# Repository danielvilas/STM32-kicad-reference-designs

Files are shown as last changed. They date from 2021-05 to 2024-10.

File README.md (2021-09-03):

# STM32-kicad-reference-designs

{:toc}

Reference Designs for STM32 in KiCad

These projects are designed as reference Design for copy subsheets and reuse wherever needed.

Ideally the board will allways the same (DevelBoard) modified to use the current chip. But as needed the reference design will be updated to use different elements, such as Ethernet, Can Bus, usb.

## Folder structure

The Folders under this repository are defined to follow this standard:
```
 .
├── [FAMILY]
│   ├── [LINE]
|   |   ├──Firmware
|   |   |  └──[*] Platformio Code
|   |   ├──[CHIP]_[Board]
|   |   |  └──[*] Kicad Project
|   |   └──README.MD
│   ├── [LINE] Other line 
|   |   └── ...
|   ...  
│   └──PlatformIo
│       ├──install.sh
│       ├──[Board].json
|       ├──[variantn].h
|       ├──[variantn].cpp
|       └── ... More boards and variants
└──[FAMILY] Other family
├──... More families
...

```
The folder estructure is based on the STM32 organization of theirs chips, this are based on families and lines. This relates to the name of the chip having the code `STM32FFLLCCCC'  where F is the FamiliyCode, L the line and C the chip code.

|Terms|Descritpion|examples|
|:--|:--|:--|
|Family |Stm32 Family | STM32F4, STM32G0 |
|Line| Stm32 Line name, chooses a model within the family| STM32F103, STM32G051|
|Chip| Current Chip, defines package, ram, rom,... inside the line| STM32F103CBT8, STM32G051C8U6|
|Firmware| Platform.io project for all boards on this family. Create envorinments for each| see notes|
|`[CHIP]_[BOARD]`| Kicad Project of board | see notes|
|README.md| each line should have it's own document to explay all the boards, what the firmware does, and the compatible chips (testeds)|
|PlatformIo|On this folder must be all the files to install the boards in PlatformIo.|b|

### Chip compatibility
By default, and as far it is indicated by ST, all the chips with the same package are interchangeables, at least at pcb level. That means that the power pins are on the same posititions and the same for the io ones.

> **_NOTE:_**  Some lines/families needs some minor changes on power pins, but the io pins mantains the positions. Check datasheets

Tested chips, should be on the README.md file of the line.

> **_NOTE:_**  This applies to hardware, not at software. update the firmware accordiling

### Firmware Notes
The firmware should be unique for the line and configured by environments on Platformio. In the case two firmwares are needed, then it will be explained on the README.MD.

The enviroments should be based on the "Generic" boards of platform.io with the defines for use the clock correctly. Even if it is based on another boards, (such as blackpill) in this cases it is correct to have two environments for that board (generic and the original board).

The environments must be explained on the README.md of the line.

The bare minimum firmware must have a blinking led and serial output (UART or USB). If the board has more components (CAN, ETH0,...) the firmware should select them by defines and have the component it's own set of files. 

### Board folder Notes
As stated before, there are compatible chips, cappable of drop-ons replacement. When a fully compatible chip is found, there is no need to copy all the board. But the folder for both chips must exists. When this case ocurrs, ensure that:

* On the original board, include notes on the schematic to include the new chip.
* On the line README.md of the original board, include the chip on the compatible chips found
* On the folder of the new chip, include:
  * Link to the current folder
  * README.MD explaing when was detected, to which, and which versions of the board are tested.
* On the line README.md of the new board document the board is the same of...

> **_NOTE:_**  Remebember that only applies to hardware, the new line must have it's own firmware, with the new chip environment.

## Kicad Project Rules
The objective is to have a series of schemeatic pages to easily import onto new projects.

The main project must only contain:
* Mount holes, or similar
* Debug Leds
* Board related connectors
* Zone for (general) power distribution, or subpage if needed
* Each functional component in one SubPage
* Mapping to the project especific pin/net names

Inside each sub page, one per functional component:
* The bare minimun componentes
* All the required connectors related to the function (SWD, ETH, USB, ...)
* Blocks separated by zones
* Herarchichal pins must be named as low level (chip) possible
* Specific power distribution as a zone, but subpage if needed

Good rules indicate to have all the conectors on the main page, but on this project we search to have a library of schematics ready to use, so it is better to have the required connectors on the same page of the functionality.

## Status of Boards

|Family|Line|Board|Status|
|:--|:--|:--|:--|
|F0|STM32F030|STM32F030K6T6|tested, updated needed|
|F1|STM32F103|STM32F103C8T8|Not implemented, tested old version|
|G0|STM32G051|STM32G051C8U6|Only in design phase|

## Change Log

* 25/05/2021 Initial Commits
  * Copy STM32F103 Devel Board from Digital Trains
* 04/08/2021 Re-Structuration
  * Creation of the structure of folders
  * Update Kicad to sub-pages
  * Added STM32G051
* 03/09/2021 Added F030
  * Added an F030
  * Created Files for board integration on pio

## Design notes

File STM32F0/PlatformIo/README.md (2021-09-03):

# Platformio Integration
This folder contains all the files necessaries to run the board with PlatformIo.

The trikcy part of this device is that PlatformIO's `platform-ststm32` doesn't have an generic boards for 030k6 but `framework-arduinoststm32` has it.
Also there is no board with K6 Chip version, it has with T8

run `install.sh` to copy all the files to build the firmware

## genericSTM32F030k6
As stated before the `platform-ststm32` only needs the board definition because `framework-arduinoststm32` already has the variant files but without the ld scripts so we use the ld script from other 030 chips.

## STM32F030K6T6TR_Devel
The board developed on this repository
* Clock HSE of 8MHZ
* UART1 On PA9/PA10
* LED_BUILTIN on PB5

> **_NOTE:_**  Clock Config is copied from STM Cube Ide and only with UART clock, other pherphials may need tweak the function.

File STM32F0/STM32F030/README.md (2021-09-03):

# STM32F030

## Known cons
This chip bootloader doesn't support USB DFU. Needs to use STLink allways.

## Board STM32F030K6T6TR_Devel
This board schematic is losely based STM32F103CBT8_Devel

## Firmware
Not Changed from STM32F103CBT8_Devel
TODO

The firmware only blinks a led, toggling it every 1 second and prints on the serial a text on each change.

Environments:
|name|description|notes|
|:--|:--|:--|
|STM32F030K6T6TR_Devel| Board STM32F030K6T6TR_Devel| Custom Board|
|STM32F030_Devel_generic| Code for the generic board config file | Without HSE, all defines needed to work with STM32F030K6T6TR_Devel |

## Compatibility
General compatibility with all STM32F lines. Not tested

## Current Status
Tested, but need update

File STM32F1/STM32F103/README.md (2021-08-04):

# STM32F103

## Known cons
This chip bootloader doesn't support USB DFU. Needs to use STLink allways.

## Board STM32F103CBT8_Devel
This board schematic is losely based on the NUCLEO-F103RB board, but only the part of the MCU and added an USB interface and a SWD connector.

## Firmware
The firmware only blinks a led, toggling it every 1 second and prints on the serial a text on each change.

Environments:
|name|description|notes|
|:--|:--|:--|
|STM32F103_Devel| Board STM32F103CBT8_Devel| Uses Serial USB. Led on PB5. Based on generic board|
|NUCLEO-F103RB| Nucelo Board| Uses Serial throught debug chip|

## Compatibility
General compatibility with all STM32F lines. Not tested

## Current Status
This board has not been implemented. Was tested a previous board. this boards is an evolution with the changes:
* The schematic is almost the same, but with an SWD 1.27 added
* The PA and PB connectors are well possitioned 
* The silk layer have been improved, with more usefull information.

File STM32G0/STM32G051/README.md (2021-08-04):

# STM32G051
This line does no support USB. So the board is without usb but with a FTDI Header

## Status
This board and firmware is under development. Is a Work In Progress. Not builded.

## Compatibility
This chip is only compatbile with STMG0 line

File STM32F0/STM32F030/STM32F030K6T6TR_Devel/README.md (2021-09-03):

# STM32F103 Devel Board
STM32F103 Board for development with STM32F103CB chip. The intention of this project is to have my own basic board for this chip in order to design custom boards which use the STM32103CB chip.

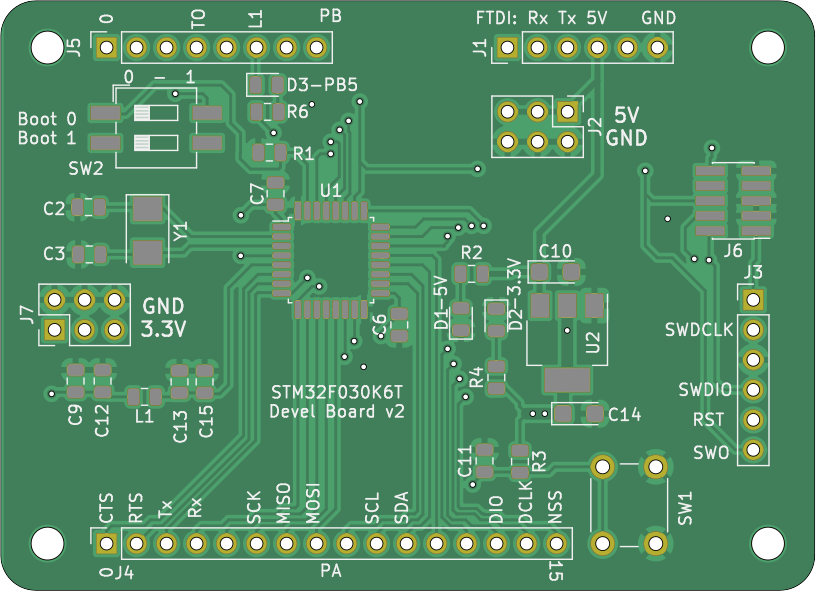
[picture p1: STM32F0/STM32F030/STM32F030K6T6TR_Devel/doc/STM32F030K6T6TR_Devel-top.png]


## Board specs:
* CHIP STM32F103CBT6
  * 128KB Flash / 20 KB RAM
  * 72 MHz Core
  * [https://www.st.com/en/microcontrollers-microprocessors/stm32f103cb.html](https://www.st.com/en/microcontrollers-microprocessors/stm32f103cb.html)
* Board Cristals:
  * HSE Clock: 8 Mhz
  * LSE Clokc: 32.768KHz
* Ports:
  * USB Port
  * SWD 6 pins 2.54
  * SWD 10 pins 1.27
  * PortA and PortB 16 pins 2.54
* 3.3V Regulator:
  * AMS1117-3.3
* Indicator LEDs:
  * 5V
  * 3.3V
  * PB5 (ligh on low)
* Boot selector
  * Boot0 and Boot1 to jumper pins

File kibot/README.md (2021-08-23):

# Kibot Scripts
This folder contains the kibot scripts in order to document the projects. So, all projects have the same documentation.

## Install

```
sudo apt install xvfb recordmydesktop xdotool librsvg2-bin imagemagick
curl -OL https://github.com/INTI-CMNB/InteractiveHtmlBom/releases/download/v2.3.4-2/interactivehtmlbom.inti-cmnb_2.3.4-2_all.deb 
sudo apt install ./interactivehtmlbom.inti-cmnb_2.3.4-2_all.deb
rm ./interactivehtmlbom.inti-cmnb_2.3.4-2_all.deb

pip3 install kibot --no-compile
pip3 install kikit pcbdraw

```

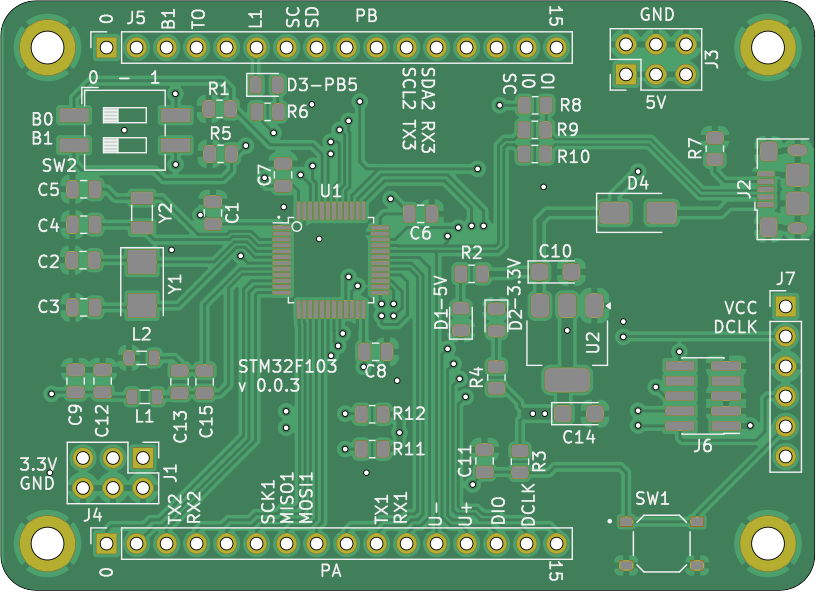
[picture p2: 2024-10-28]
STM32F1/STM32F103/STM32F103CBT8_Devel/doc/STM32103_Devel-top.png

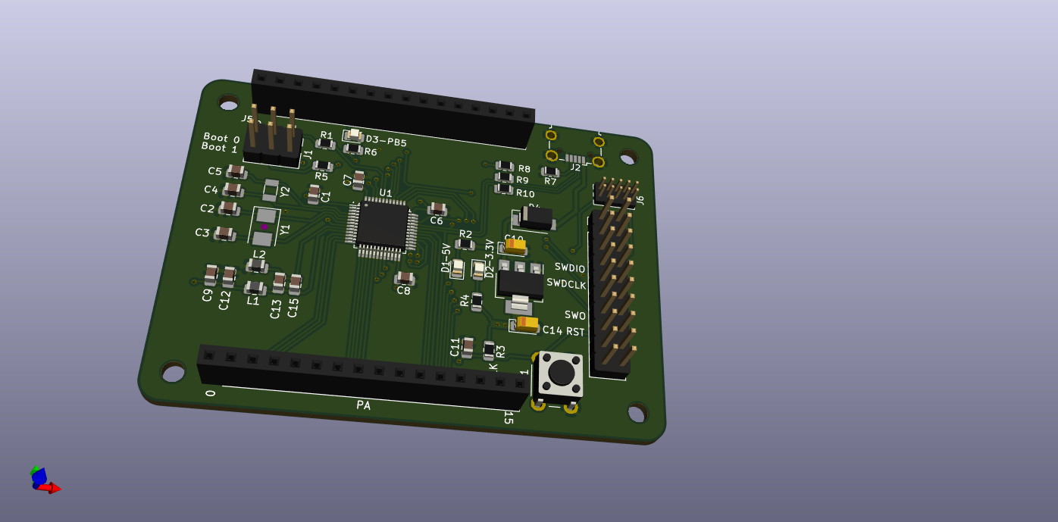
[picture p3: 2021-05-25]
STM32F1/STM32F103/STM32F103CBT8_Devel/STM32103_Devel.png

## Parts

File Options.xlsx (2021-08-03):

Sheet: List
List of MCUs selection: 55 items. Database version: Mon Feb 08 14:35:07 CET 2021
Favorite | Part No | Ali Board | LCSC | Precio | Basic | Package | Flash | RAM | IO | Freq.
 | STM32F205RB |  | C8364 STM32F205RBT6 | 3.23 | Extended (NS) | LQFP64 (10x10mm) | 128 kBytes | 64 kBytes | 51 | 120 MHz
 | STM32F205RC |  | C47520 STM32F205RCT6 | 2.95 | Extended (2) | LQFP64 (10x10mm) | 256 kBytes | 96 kBytes | 51 | 120 MHz
 | STM32F205RE |  | C66278 STM32F205RET6 | 3.2 | Extended (NS) | LQFP64 (10x10mm) | 512 kBytes | 128 kBytes | 51 | 120 MHz
 | STM32F205RF |  |  |  |  | LQFP64 (10x10mm) | 768 kBytes | 128 kBytes | 51 | 120 MHz
 | STM32F205VB |  |  |  |  | LQFP100 (14x14mm) | 128 kBytes | 64 kBytes | 82 | 120 MHz
 | STM32F205VC |  | C95445 STM32F205VCT6 | 5.6 | Extended (NS) | LQFP100 (14x14mm) | 256 kBytes | 96 kBytes | 82 | 120 MHz
 | STM32F205VE |  | C81869 STM32F205VET6 | 5.2 | Extended (NS) | LQFP100 (14x14mm) | 512 kBytes | 128 kBytes | 82 | 120 MHz
 | STM32F205VF |  | C443970 STM32F205VFT6 | 5.2 | Extended (NS) | LQFP100 (14x14mm) | 768 kBytes | 128 kBytes | 82 | 120 MHz
 | STM32F205VG |  | C44390 STM32F205VGT6 | 6.13 | Extended (NS) | LQFP100 (14x14mm) | 1024 kBytes | 128 kBytes | 82 | 120 MHz
 | STM32F207VC |  | C62447 STM32F207VCT6 | 5.6 | Extended (NS) | LQFP100 (14x14mm) | 256 kBytes | 128 kBytes | 82 | 120 MHz
 | STM32F207VE |  | C59126 STM32F207VET6 | 4.4 | Extended (1) | LQFP100 (14x14mm) | 512 kBytes | 128 kBytes | 82 | 120 MHz
 | STM32F207VF |  |  |  |  | LQFP100 (14x14mm) | 768 kBytes | 128 kBytes | 82 | 120 MHz
 | STM32F207VG |  | C12089 STM32F207VGT6 | 9 | Extended (1) | LQFP100 (14x14mm) | 1024 kBytes | 128 kBytes | 82 | 120 MHz
 | STM32F215RE |  |  |  |  | LQFP64 (10x10mm) | 512 kBytes | 128 kBytes | 51 | 120 MHz
 | STM32F215RG |  |  |  |  | LQFP64 (10x10mm) | 1024 kBytes | 128 kBytes | 51 | 120 MHz
 | STM32F215VE |  |  |  |  | LQFP100 (14x14mm) | 512 kBytes | 128 kBytes | 82 | 120 MHz
 | STM32F215VG |  |  |  |  | LQFP100 (14x14mm) | 1024 kBytes | 128 kBytes | 82 | 120 MHz
 | STM32F217VE |  |  |  |  | LQFP100 (14x14mm) | 512 kBytes | 128 kBytes | 82 | 120 MHz
 | STM32F217VG |  |  |  |  | LQFP100 (14x14mm) | 1024 kBytes | 128 kBytes | 82 | 120 MHz
 | STM32F405RG |  |  |  |  | LQFP64 (10x10mm) | 1024 kBytes | 192 kBytes | 51 | 168 MHz
 | STM32F405VG |  | C56621 STM32F405VGT6 | 5 | Extended (NS) | LQFP100 (14x14mm) | 1024 kBytes | 192 kBytes | 82 | 168 MHz
 | STM32F407VE |  | C28730 STM32F407VET6 | 13 | Basic (1) | LQFP100 (14x14mm) | 512 kBytes | 192 kBytes | 82 | 168 MHz
 | STM32F407VG |  | C12345 STM32F407VGT6 | 17 | Basic (300) | LQFP100 (14x14mm) | 1024 kBytes | 192 kBytes | 82 | 168 MHz
 | STM32F413CH |  |  |  |  | UFQFPN48 (7x7mm) | 1536 kBytes | 320 kBytes | 36 | 100 MHz
 | STM32F413RH |  |  |  |  | LQFP64 (10x10mm) | 1536 kBytes | 320 kBytes | 50 | 100 MHz
 | STM32F413VG |  | C1337757 STM32F413VGH6 | 9 | Extended (NS) | LQFP100 (14x14mm) | 1024 kBytes | 320 kBytes | 81 | 100 MHz
 | STM32F415RG |  | C124726 STM32F415RGT6 | 6.7 | Extended (NS) | LQFP64 (10x10mm) | 1024 kBytes | 192 kBytes | 51 | 168 MHz
 | STM32F415VG |  | C118210 STM32F415VGT6 | 12.34 | Extended (300) | LQFP100 (14x14mm) | 1024 kBytes | 192 kBytes | 82 | 168 MHz
 | STM32F417VE |  |  |  |  | LQFP100 (14x14mm) | 512 kBytes | 192 kBytes | 82 | 168 MHz
 | STM32F417VG |  |  |  |  | LQFP100 (14x14mm) | 1024 kBytes | 192 kBytes | 82 | 168 MHz
 | STM32F427VG |  | C117815 STM32F427VGT6 | 18 | Extended (300) | LQFP100 (14x14mm) | 1024 kBytes | 256 kBytes | 82 | 180 MHz
 | STM32F427VI |  | C57097 STM32F427VIT6 | 10.3 | Extended (NS) | LQFP100 (14x14mm) | 2048 kBytes | 256 kBytes | 82 | 180 MHz
 | STM32F429VE |  | C95447 STM32F429VET6 | 5.1 | Extended (NS) | LQFP100 (14x14mm) | 512 kBytes | 256 kBytes | 82 | 180 MHz
 | STM32F429VG |  | C95448 STM32F429VGT6 | 7 | Extended (NS) | LQFP100 (14x14mm) | 1024 kBytes | 256 kBytes | 82 | 180 MHz
 | STM32F429VI |  | C92002 STM32F429VIT6 | 30 | Extended (13) | LQFP100 (14x14mm) | 2048 kBytes | 256 kBytes | 82 | 180 MHz
 | STM32F437VG |  |  |  |  | LQFP100 (14x14mm) | 1024 kBytes | 256 kBytes | 82 | 180 MHz
 | STM32F437VI |  |  |  |  | LQFP100 (14x14mm) | 2048 kBytes | 256 kBytes | 82 | 180 MHz
 | STM32F439VG |  |  |  |  | LQFP100 (14x14mm) | 1024 kBytes | 256 kBytes | 82 | 180 MHz
 | STM32F439VI |  |  |  |  | LQFP100 (14x14mm) | 2048 kBytes | 256 kBytes | 82 | 180 MHz
 | STM32F446RC |  | C1338449 STM32F446RCT7 | 6.1 | Extended (NS) | LQFP64 (10x10mm) | 256 kBytes | 128 kBytes | 50 | 180 MHz
 | STM32F446RE |  | C69336 STM32F446RET6 | 8.5 | Extended (NS) | LQFP64 (10x10mm) | 512 kBytes | 128 kBytes | 50 | 180 MHz
 | STM32F446VC |  | C2827817 STM32F446VCT6 | 8.2 | Extended (NS) | LQFP100 (14x14mm) | 256 kBytes | 128 kBytes | 81 | 180 MHz
 | STM32F446VE |  | C91929 STM32F446VET6 | 10.1 | Extended (100) | LQFP100 (14x14mm) | 512 kBytes | 128 kBytes | 81 | 180 MHz
 | STM32F469VE |  |  |  |  | LQFP100 (14x14mm) | 512 kBytes | 384 kBytes | 71 | 180 MHz
 | STM32F469VG |  | C503095 STM32F469VGT6 | 11.2 | Extended (NS) | LQFP100 (14x14mm) | 1024 kBytes | 384 kBytes | 71 | 180 MHz
 | STM32F469VI |  |  |  |  | LQFP100 (14x14mm) | 2048 kBytes | 384 kBytes | 71 | 180 MHz
 | STM32F479VG |  |  |  |  | LQFP100 (14x14mm) | 1024 kBytes | 384 kBytes | 71 | 180 MHz
 | STM32F479VI |  |  |  |  | LQFP100 (14x14mm) | 2048 kBytes | 384 kBytes | 71 | 180 MHz

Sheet: Hoja3
 | Part | Stock | Price | Basic | Precio 5 | USB | CAN | I2S | I2C | SPI | SDIO
X | STM32F207VET6 | 1 | 4.40 € |  | 25.0005 | 1 | 2 | 2 | 3 | 3 | 1
 | STM32F373CCT6 | 2 | 6.64 € |  | 36.1945 | 1 | 1 | 2 | 2 | 3 | 0
X | STM32F207VGT6 | 1 | 9.03 € |  | 48.1405 | 1 | 2 | 2 | 3 | 3 | 1
X | STM32F407ZGT6 | 1 | 11.67 € |  | 61.3585 | 2 | 2 | 2 | 3 | 3 | 1
X | STM32F407VET6 | 1 | 12.82 € | 1 | 64.1135 | 2 | 2 | 2 | 3 | 2 | 1
 | STM32F429BIT6 | 24 | 14.94 € |  | 77.7185 | 2 | 2 | 2 | 3 | 6 | 1
 | STM32F407VGT6 | 311 | 17.90 € | 1 | 89.4765 | 1 | 2 | 2 | 3 | 3 | 1
 | STM32F103ZET6 | 106 | 17.90 € | 1 | 89.477 | 1 | 1 | 2 | 2 | 3 | 1
 | STM32F103RCT6 | 1 | 21.03 € | 1 | 105.1345 | 1 | 1 | 2 | 2 | 3 | 1
 | STM32F427ZGT6 | 6296 | 22.56 € |  | 115.795 | 2 | 2 | 2 | 3 | 6 | 1
 | STM32F107VCT6 | 208 | 23.26 € | 1 | 116.3195 | 1 | 2 | 2 | 1 | 3 | 0
 | STM32F103VET6 | 324 | 26.84 € | 1 | 134.2175 | 1 | 1 | 2 | 2 | 3 | 1
 | STM32F103VCT6 | 445 | 28.63 € | 1 | 143.1625 | 1 | 1 | 2 | 2 | 3 | 1
 | STM32F103C6T6A | 1 | 1.38 € |  | 9.916 | 1 | 1 | 0 | 1 | 1 | 0
 | STM32F103R8T6 | 1382 | 9.05 € | 1 | 45.265 | 1 | 1 | 0 | 2 | 2 | 0
 | STM32F103C8T6 | 7257 | 10.54 € | 1 | 52.69 € | 1 | 1 | 0 | 2 | 2 | 0
 | STM32F103VBT6 | 42 | 23.26 € | 1 | 116.3235 | 1 | 1 | 0 | 2 | 2 | 0

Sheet: List_2
List of MCUs selection: 55 items. Database version: Mon Feb 08 14:35:07 CET 2021
Favorite | Part No | Ali Board | LCSC | Precio | Basic | Precio 5 | Package | Flash | RAM | IO | Freq.
 | STM32F205RB |  | C8364 STM32F205RBT6 | 3.23 | Extended (NS) | 19.15 | LQFP64 (10x10mm) | 128 kBytes | 64 kBytes | 51 | 120 MHz
 | STM32F205RC |  | C47520 STM32F205RCT6 | 2.95 | Extended (2) | 17.75 | LQFP64 (10x10mm) | 256 kBytes | 96 kBytes | 51 | 120 MHz
 | STM32F205RE |  | C66278 STM32F205RET6 | 3.2 | Extended (NS) | 19 | LQFP64 (10x10mm) | 512 kBytes | 128 kBytes | 51 | 120 MHz
 | STM32F205VC |  | C95445 STM32F205VCT6 | 5.6 | Extended (NS) | 31 | LQFP100 (14x14mm) | 256 kBytes | 96 kBytes | 82 | 120 MHz
 | STM32F205VE |  | C81869 STM32F205VET6 | 5.2 | Extended (NS) | 29 | LQFP100 (14x14mm) | 512 kBytes | 128 kBytes | 82 | 120 MHz
 | STM32F205VF |  | C443970 STM32F205VFT6 | 5.2 | Extended (NS) | 29 | LQFP100 (14x14mm) | 768 kBytes | 128 kBytes | 82 | 120 MHz
 | STM32F205VG |  | C44390 STM32F205VGT6 | 6.13 | Extended (NS) | 33.65 | LQFP100 (14x14mm) | 1024 kBytes | 128 kBytes | 82 | 120 MHz
 | STM32F207VC |  | C62447 STM32F207VCT6 | 5.6 | Extended (NS) | 31 | LQFP100 (14x14mm) | 256 kBytes | 128 kBytes | 82 | 120 MHz
 | STM32F207VE |  | C59126 STM32F207VET6 | 4.4 | Extended (1) | 25 | LQFP100 (14x14mm) | 512 kBytes | 128 kBytes | 82 | 120 MHz
 | STM32F207VG |  | C12089 STM32F207VGT6 | 9 | Extended (1) | 48 | LQFP100 (14x14mm) | 1024 kBytes | 128 kBytes | 82 | 120 MHz
 | STM32F405VG |  | C56621 STM32F405VGT6 | 5 | Extended (NS) | 28 | LQFP100 (14x14mm) | 1024 kBytes | 192 kBytes | 82 | 168 MHz
 | STM32F407VE |  | C28730 STM32F407VET6 | 13 | Basic (1) | #VALUE! | LQFP100 (14x14mm) | 512 kBytes | 192 kBytes | 82 | 168 MHz
 | STM32F407VG |  | C12345 STM32F407VGT6 | 17 | Basic (300) | #VALUE! | LQFP100 (14x14mm) | 1024 kBytes | 192 kBytes | 82 | 168 MHz
 | STM32F413VG |  | C1337757 STM32F413VGH6 | 9 | Extended (NS) | 48 | LQFP100 (14x14mm) | 1024 kBytes | 320 kBytes | 81 | 100 MHz
 | STM32F415RG |  | C124726 STM32F415RGT6 | 6.7 | Extended (NS) | 36.5 | LQFP64 (10x10mm) | 1024 kBytes | 192 kBytes | 51 | 168 MHz
 | STM32F415VG |  | C118210 STM32F415VGT6 | 12.34 | Extended (300) | 64.7 | LQFP100 (14x14mm) | 1024 kBytes | 192 kBytes | 82 | 168 MHz
 | STM32F427VG |  | C117815 STM32F427VGT6 | 18 | Extended (300) | 93 | LQFP100 (14x14mm) | 1024 kBytes | 256 kBytes | 82 | 180 MHz
 | STM32F427VI |  | C57097 STM32F427VIT6 | 10.3 | Extended (NS) | 54.5 | LQFP100 (14x14mm) | 2048 kBytes | 256 kBytes | 82 | 180 MHz
 | STM32F429VE |  | C95447 STM32F429VET6 | 5.1 | Extended (NS) | 28.5 | LQFP100 (14x14mm) | 512 kBytes | 256 kBytes | 82 | 180 MHz
 | STM32F429VG |  | C95448 STM32F429VGT6 | 7 | Extended (NS) | 38 | LQFP100 (14x14mm) | 1024 kBytes | 256 kBytes | 82 | 180 MHz
 | STM32F429VI |  | C92002 STM32F429VIT6 | 30 | Extended (13) | 153 | LQFP100 (14x14mm) | 2048 kBytes | 256 kBytes | 82 | 180 MHz
 | STM32F446RC |  | C1338449 STM32F446RCT7 | 6.1 | Extended (NS) | 33.5 | LQFP64 (10x10mm) | 256 kBytes | 128 kBytes | 50 | 180 MHz
 | STM32F446RE |  | C69336 STM32F446RET6 | 8.5 | Extended (NS) | 45.5 | LQFP64 (10x10mm) | 512 kBytes | 128 kBytes | 50 | 180 MHz
 | STM32F446VC |  | C2827817 STM32F446VCT6 | 8.2 | Extended (NS) | 44 | LQFP100 (14x14mm) | 256 kBytes | 128 kBytes | 81 | 180 MHz
 | STM32F446VE |  | C91929 STM32F446VET6 | 10.1 | Extended (100) | 53.5 | LQFP100 (14x14mm) | 512 kBytes | 128 kBytes | 81 | 180 MHz
 | STM32F469VG |  | C503095 STM32F469VGT6 | 11.2 | Extended (NS) | 59 | LQFP100 (14x14mm) | 1024 kBytes | 384 kBytes | 71 | 180 MHz

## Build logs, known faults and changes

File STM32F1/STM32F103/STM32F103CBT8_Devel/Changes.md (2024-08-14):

# Change List
List of changes done in the STM32F103 Devel Board
## Version 0.0.2 from 0.0.1
### Issues/Changes
Issues to resolve
* [X] Silk Changes
  * [X] Identify Power LEDs
  * [X] Identify Boot0 and Boot1
  * [X] Identify Pin 0 of PA y PB
  * [X] Identify LED PB5
  * [X] Paint USB and Debug pins
  * [X] I2C pins
  * [X] SPI pins
* [X] USB Improvements
  * [x] Differential Traces
  * [X] check or change USB FootPrint
* [X] PCB upgrades
  * [X] Relocate Mount Holes
  * [X] Relocate PB y PA 
  * [X] Use JTAG-10p 1.27
  * [X] Same Size as STMF030
* [x] Use dip sw to BootX pins
* [x] Power Pins

## Version 0.0.3 from 0.0.2
### Issues/Changes
* [x] THP -> SMD
  * [x] Reset btn
* [x] Dip Switches
  * [x] Better Part
* [X] MPNs
  * [X] Headers
* [X] I2c Pull Ups
* [] USB Improvements
  * [X] USB-C? -> no but changed
  * [] ESD Protection
  * [] Reenumerate

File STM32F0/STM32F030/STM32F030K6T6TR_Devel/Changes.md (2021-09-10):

# Change List
List of changes done in the STM32F030K6 Devel Board
## Version 0.0.2 
Changes from STM32F103 initial board
* [X] Chip Change 
* [X] remove unused functions (USB)
* [X] FTDI Header
* [X] Silk Changes
  * [X] Identify Power LEDs
  * [X] Identify Boot0 and Boot1
  * [X] Identify Pin 0 of PA y PB
  * [X] Identify LED PB5
* [X] Power Headers
* [X] PCB upgrades
  * [X] Relocate Mount Holes
  * [X] Relocate PB y PA 
  * [X] Use JTAG-10p 1.27
* [x] Use dip sw to BootX pins
## Version 0.0.3 
After Tested V.0.0.2
* [x] Serial on PA2/PA3
* [x] Remove big SWD port
* [x] Change SWD 1.27 for SMD
* [x] Add SWD 6 pin connector
* [ ] Identify Pins Funcions
  * [x] U\[S]ART
  * [x] I2c
  * [x] SPI

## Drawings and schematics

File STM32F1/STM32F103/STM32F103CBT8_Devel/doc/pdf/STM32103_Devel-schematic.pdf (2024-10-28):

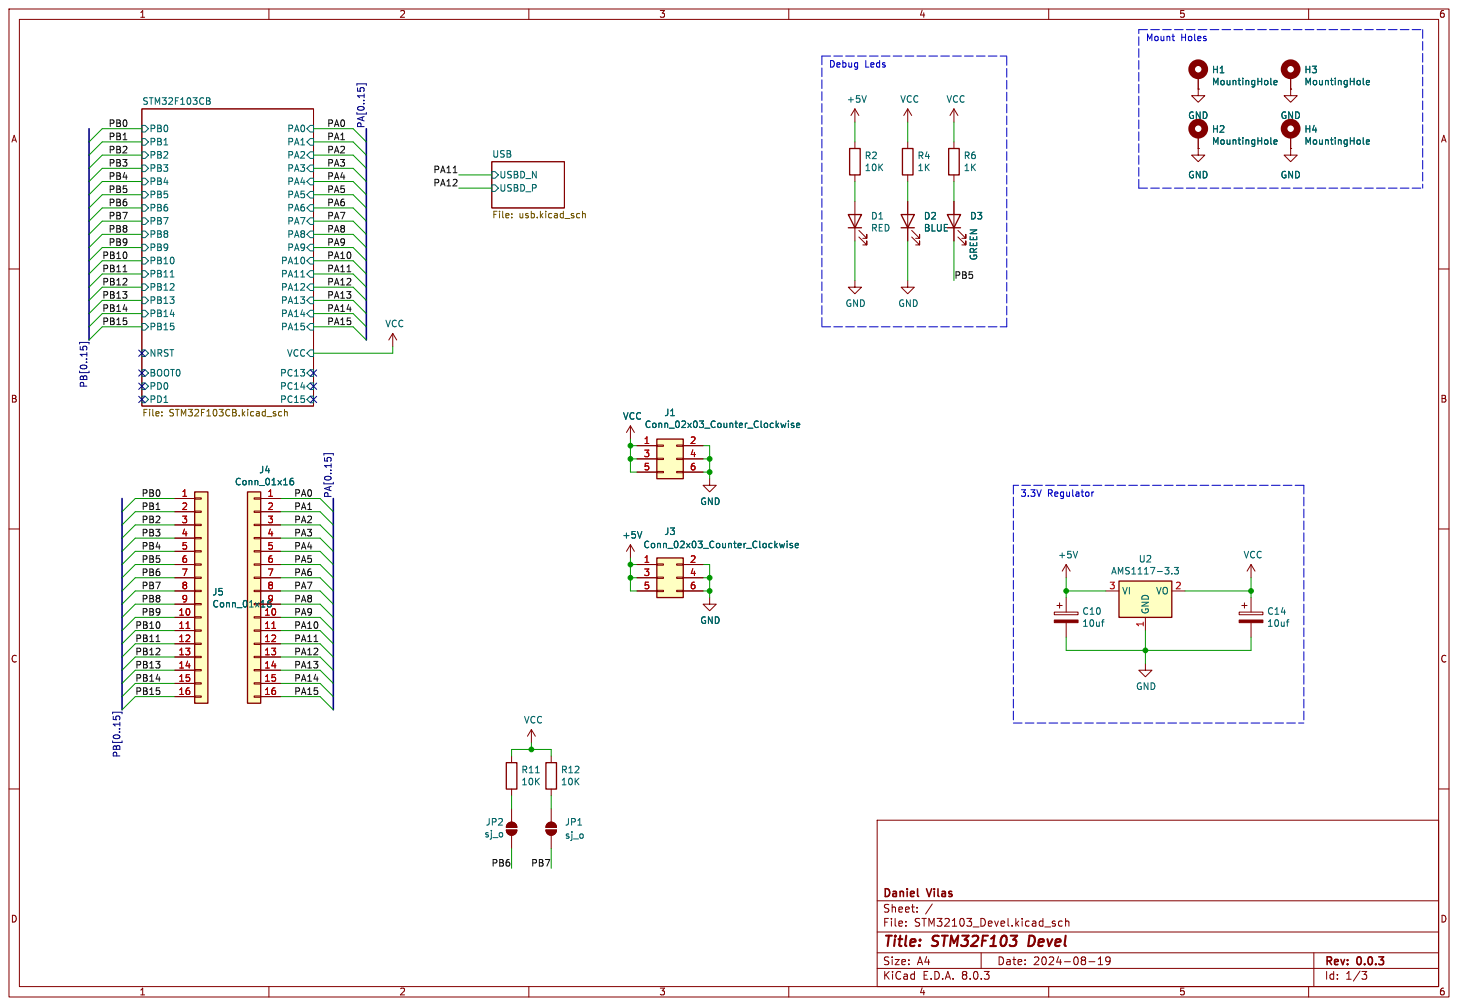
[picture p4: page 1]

Id: 1/3 Title: STM32F103 Devel File: STM32103_Devel.kicad_sch Sheet: / Daniel Vilas

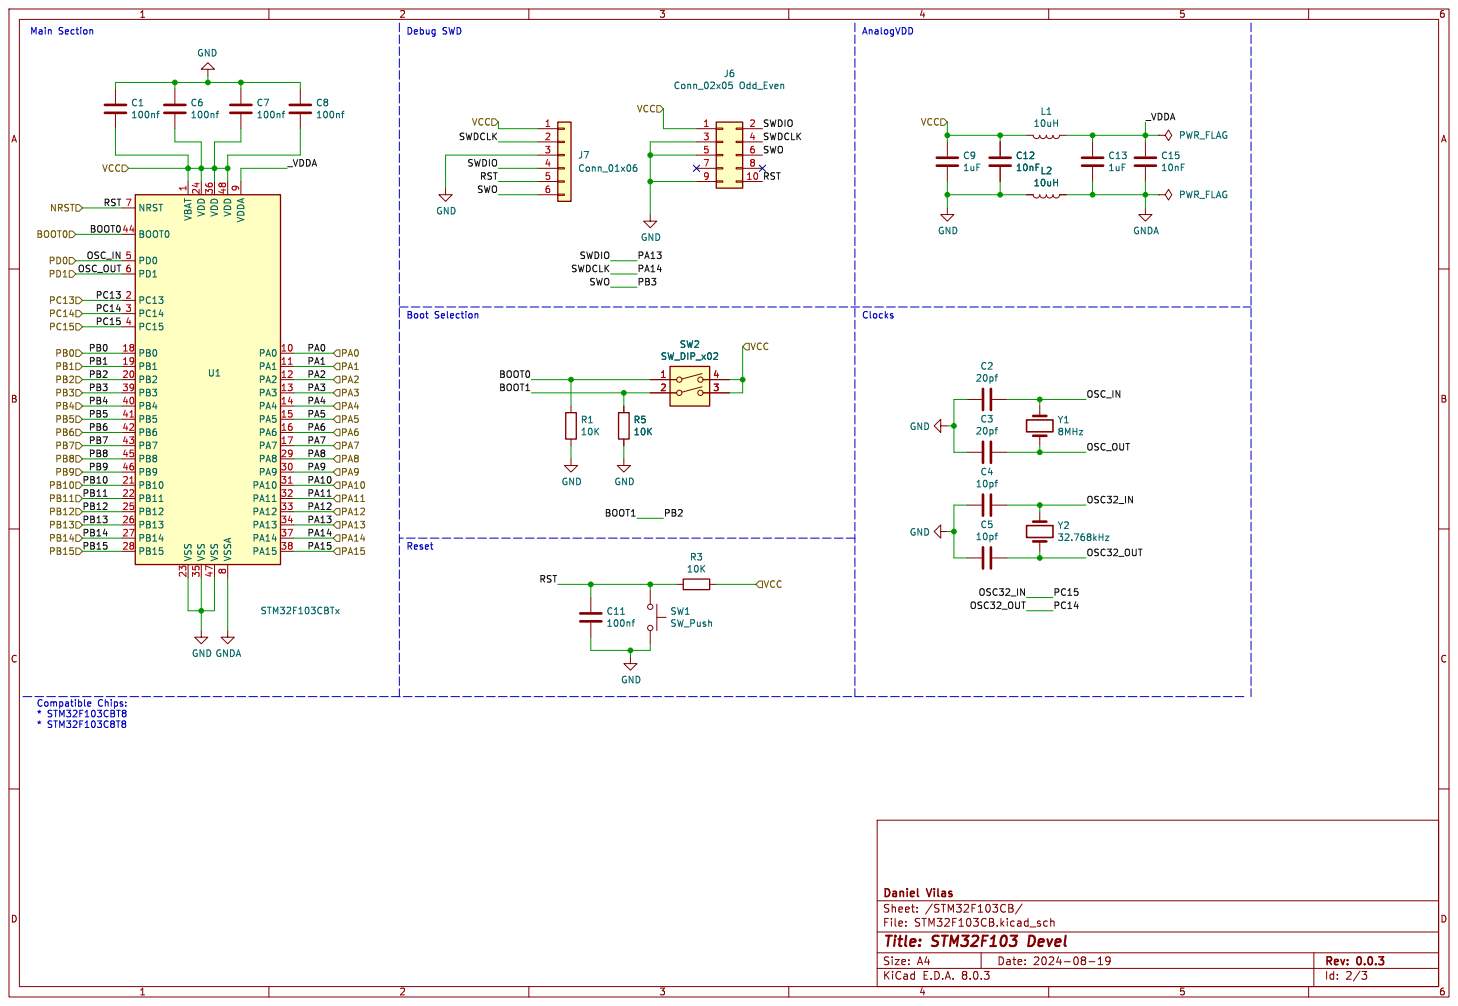
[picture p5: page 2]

1 PA0 10 PA1 11 PA2 12 PA3 13 PA4 14 PA5 15 PA6 16 PA7 17 PB0 18 PB1 19 PC13 2 PB2 20 PB10 21 PB11 22 VSS 23 VDD 24 PB12 25 PB13 26 PB14 27 PB15 28 PA8 29 PC14 3 PA9 30 PA10 31 PA11 32 PA12 33 PA13 34 VSS 35 VDD 36 PA14 37 PA15 38 PB3 39 PC15 4 PB4 40 PB5 41 PB6 42 PB7 43 BOOT0 44 PB8 45 PB9 46 VSS 47 VDD 48 PD0 5 PD1 6 NRST 7 VSSA

Id: 2/3 Title: STM32F103 Devel File: STM32F103CB.kicad_sch Sheet: /STM32F103CB/ Daniel Vilas

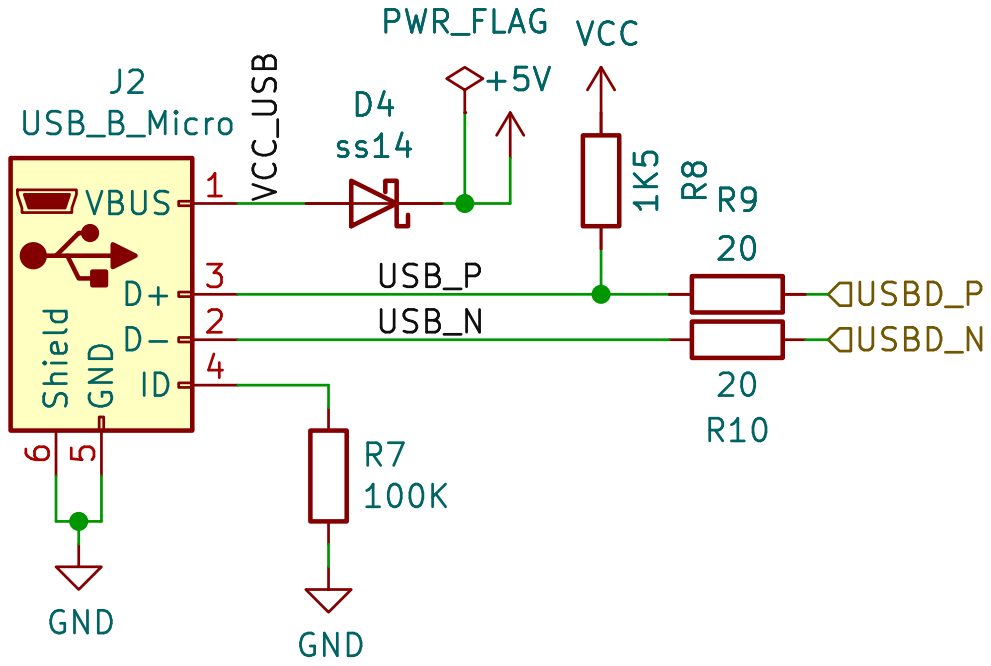
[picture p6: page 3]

Id: 3/3 Title: STM32F103 Devel File: usb.kicad_sch Sheet: /USB/ Daniel Vilas

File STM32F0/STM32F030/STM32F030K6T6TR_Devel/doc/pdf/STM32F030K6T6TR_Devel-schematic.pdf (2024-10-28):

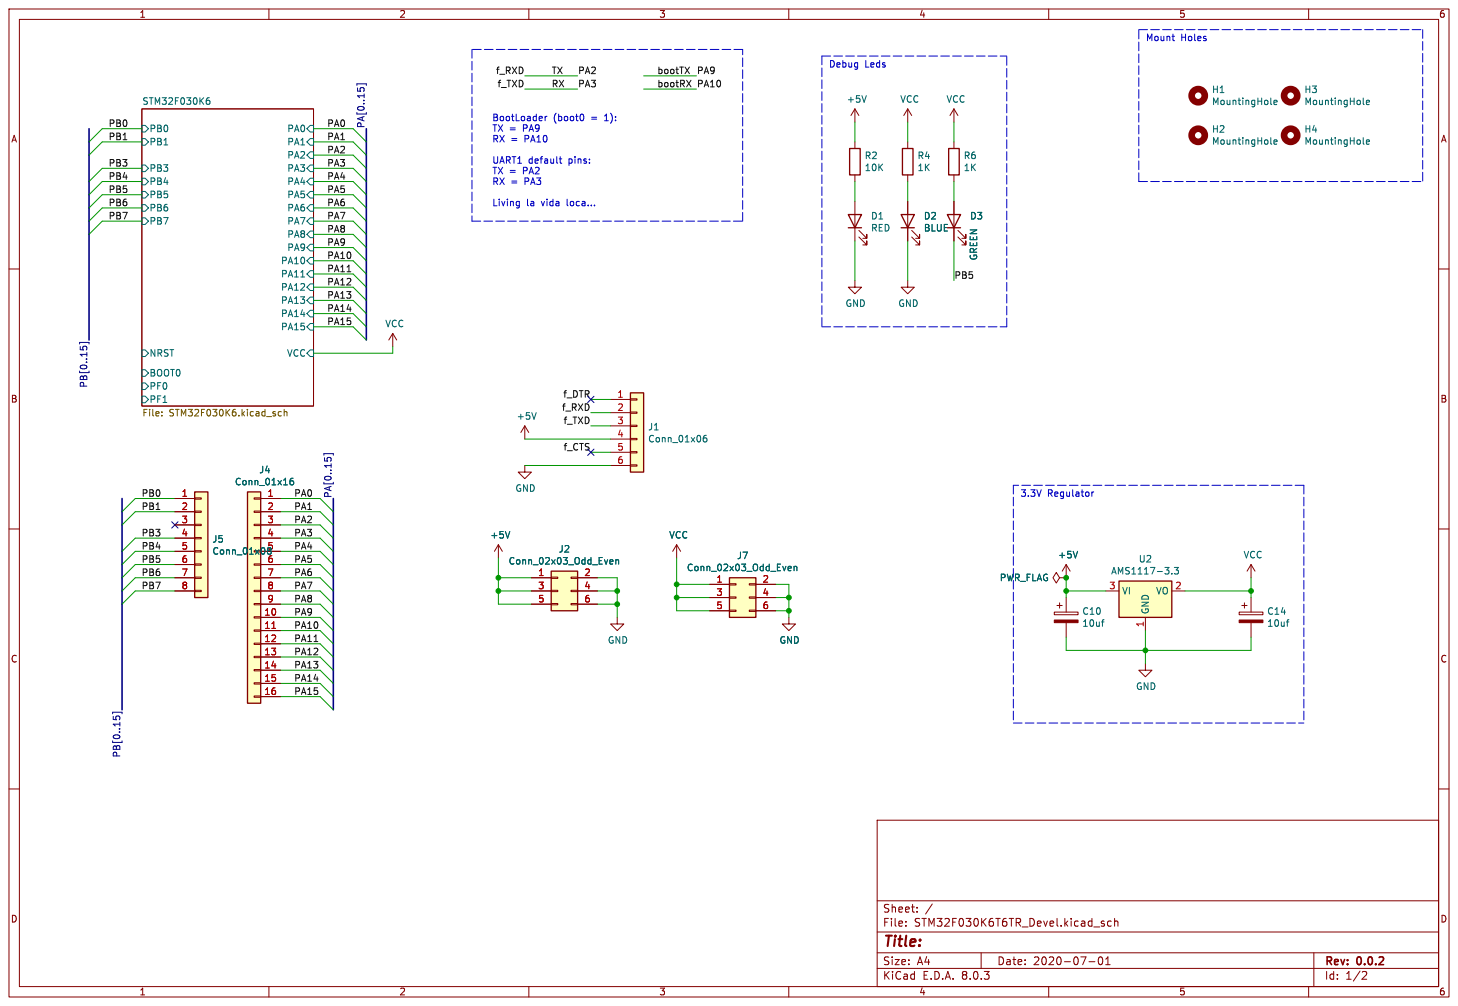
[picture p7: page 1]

Living la vida loca... J4 Conn_01x16

Id: 1/2 Title: File: STM32F030K6T6TR_Devel.kicad_sch Sheet: /

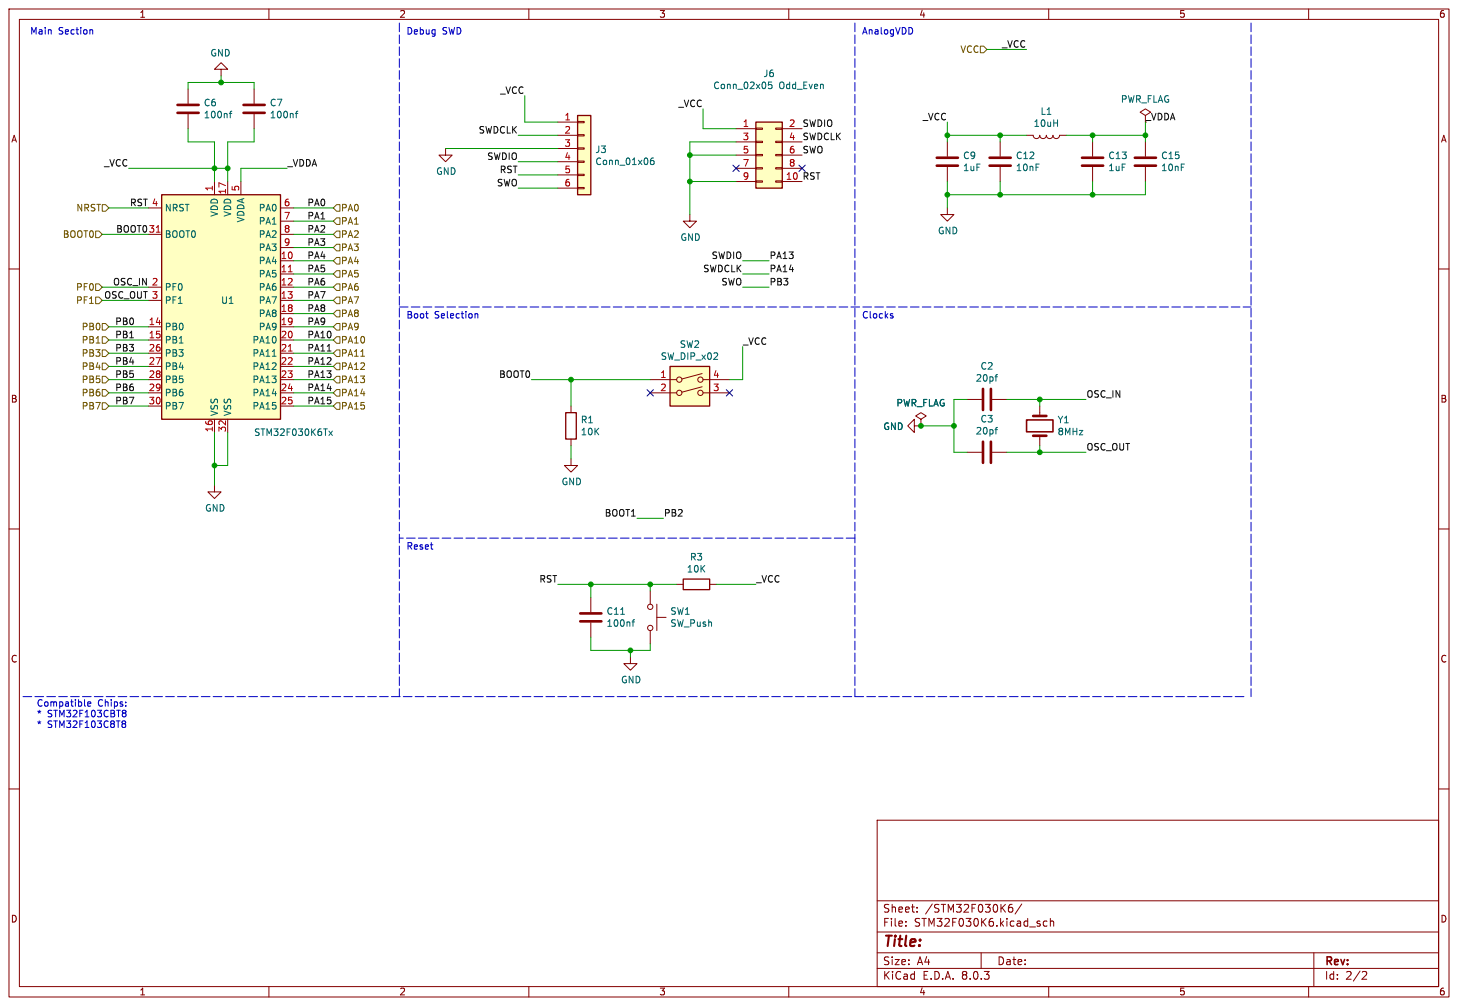
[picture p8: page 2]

1 PA4 10 PA5 11 PA6 12 PA7 13 PB0 14 PB1 15 VSS 16 VDD 17 PA8 18 PA9 19 PF0 2 PA10 20 PA11 21 PA12 22 PA13 23 PA14 24 PA15 25 PB3 26 PB4 27 PB5 28 PB6 29 PF1 3 PB7 30 BOOT0 31 VSS 32 NRST 4 VDDA

Id: 2/2 Title: File: STM32F030K6.kicad_sch Sheet: /STM32F030K6/

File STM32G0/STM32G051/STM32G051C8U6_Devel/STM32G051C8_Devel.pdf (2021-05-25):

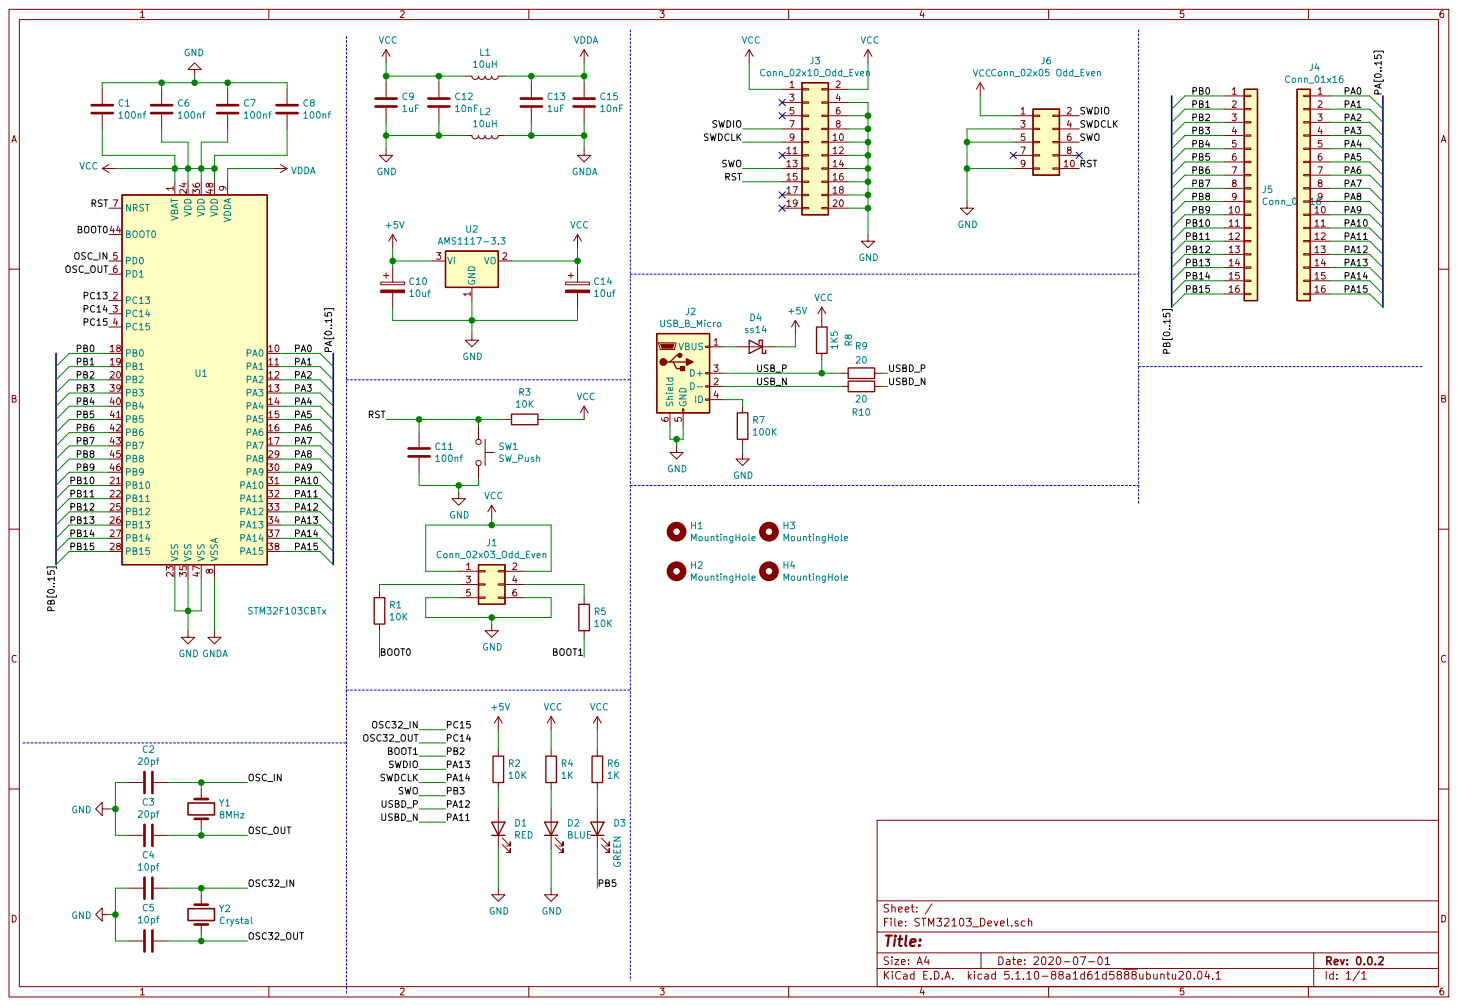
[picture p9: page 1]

1 VDD 24 VDD 36 VDD 48 VDDA

9 VSS 23 VSS 35 VSS 47 VSSA

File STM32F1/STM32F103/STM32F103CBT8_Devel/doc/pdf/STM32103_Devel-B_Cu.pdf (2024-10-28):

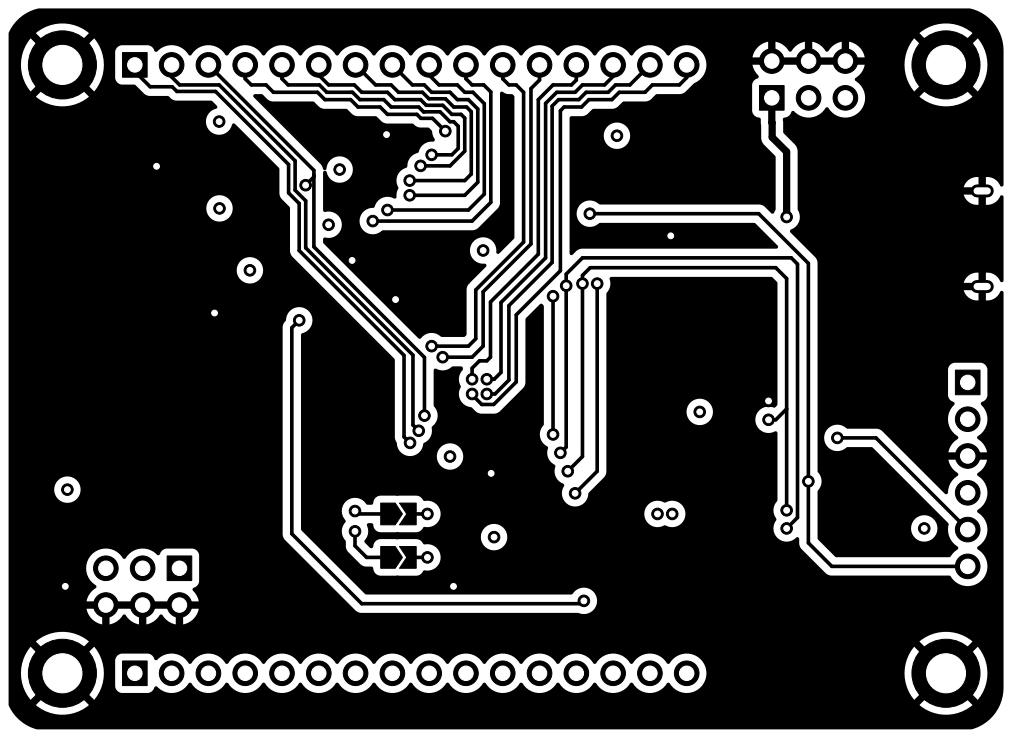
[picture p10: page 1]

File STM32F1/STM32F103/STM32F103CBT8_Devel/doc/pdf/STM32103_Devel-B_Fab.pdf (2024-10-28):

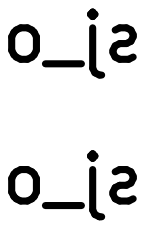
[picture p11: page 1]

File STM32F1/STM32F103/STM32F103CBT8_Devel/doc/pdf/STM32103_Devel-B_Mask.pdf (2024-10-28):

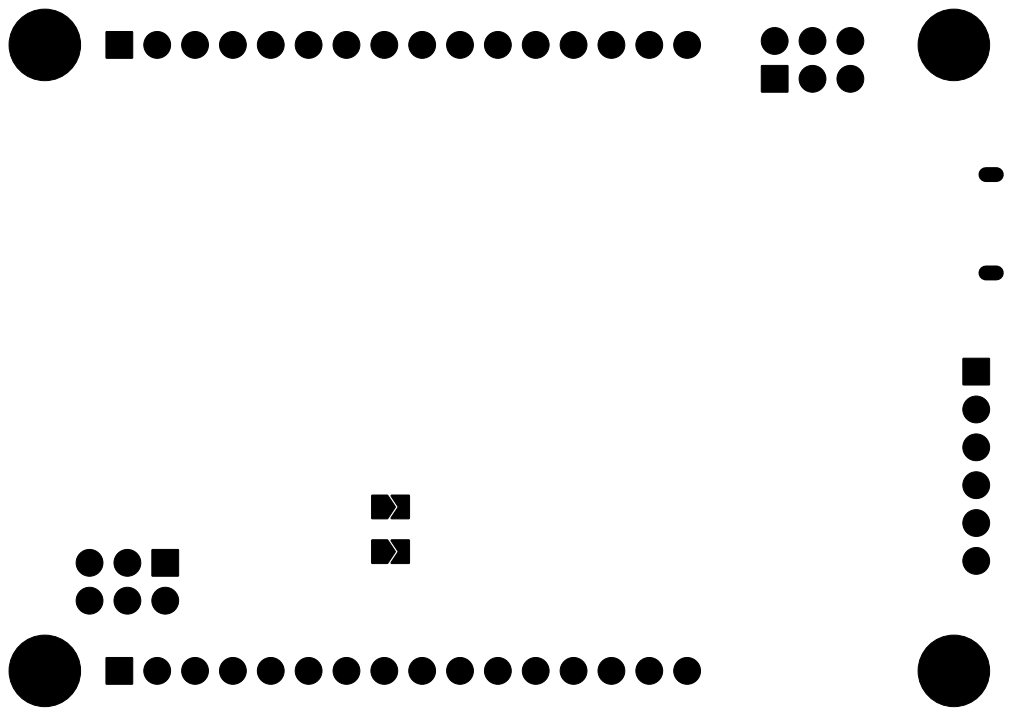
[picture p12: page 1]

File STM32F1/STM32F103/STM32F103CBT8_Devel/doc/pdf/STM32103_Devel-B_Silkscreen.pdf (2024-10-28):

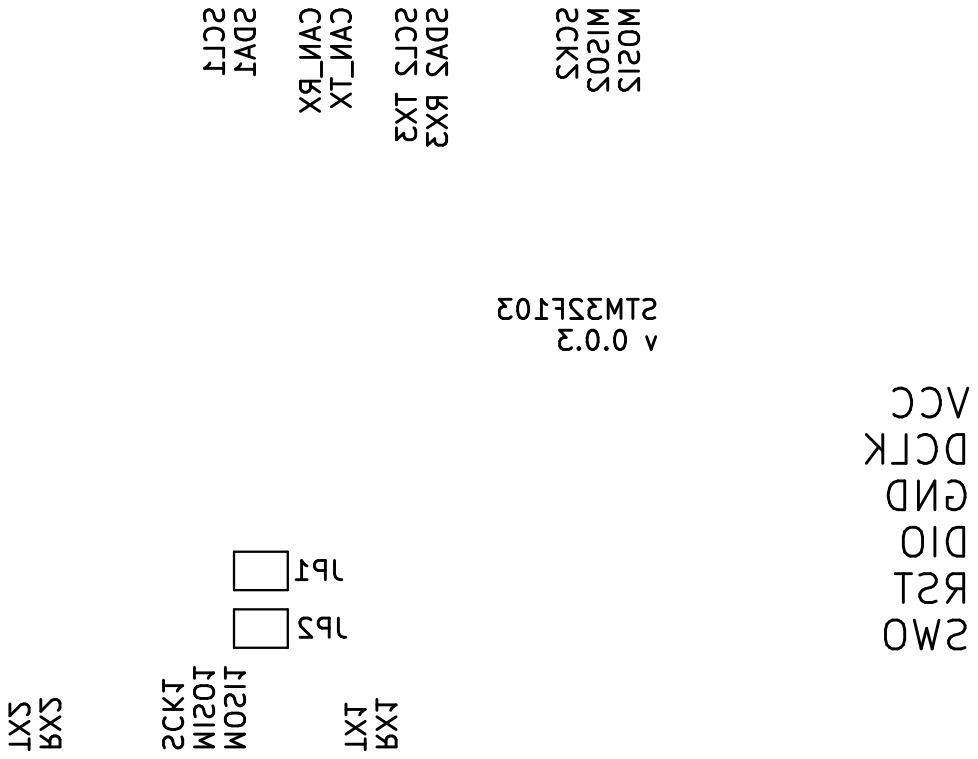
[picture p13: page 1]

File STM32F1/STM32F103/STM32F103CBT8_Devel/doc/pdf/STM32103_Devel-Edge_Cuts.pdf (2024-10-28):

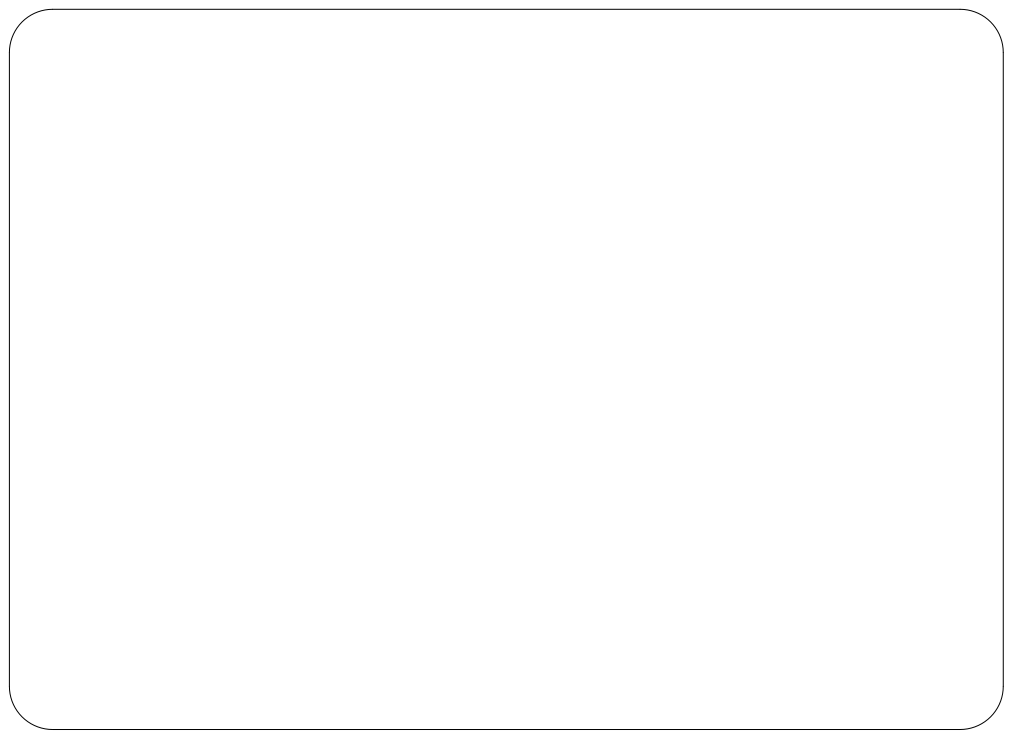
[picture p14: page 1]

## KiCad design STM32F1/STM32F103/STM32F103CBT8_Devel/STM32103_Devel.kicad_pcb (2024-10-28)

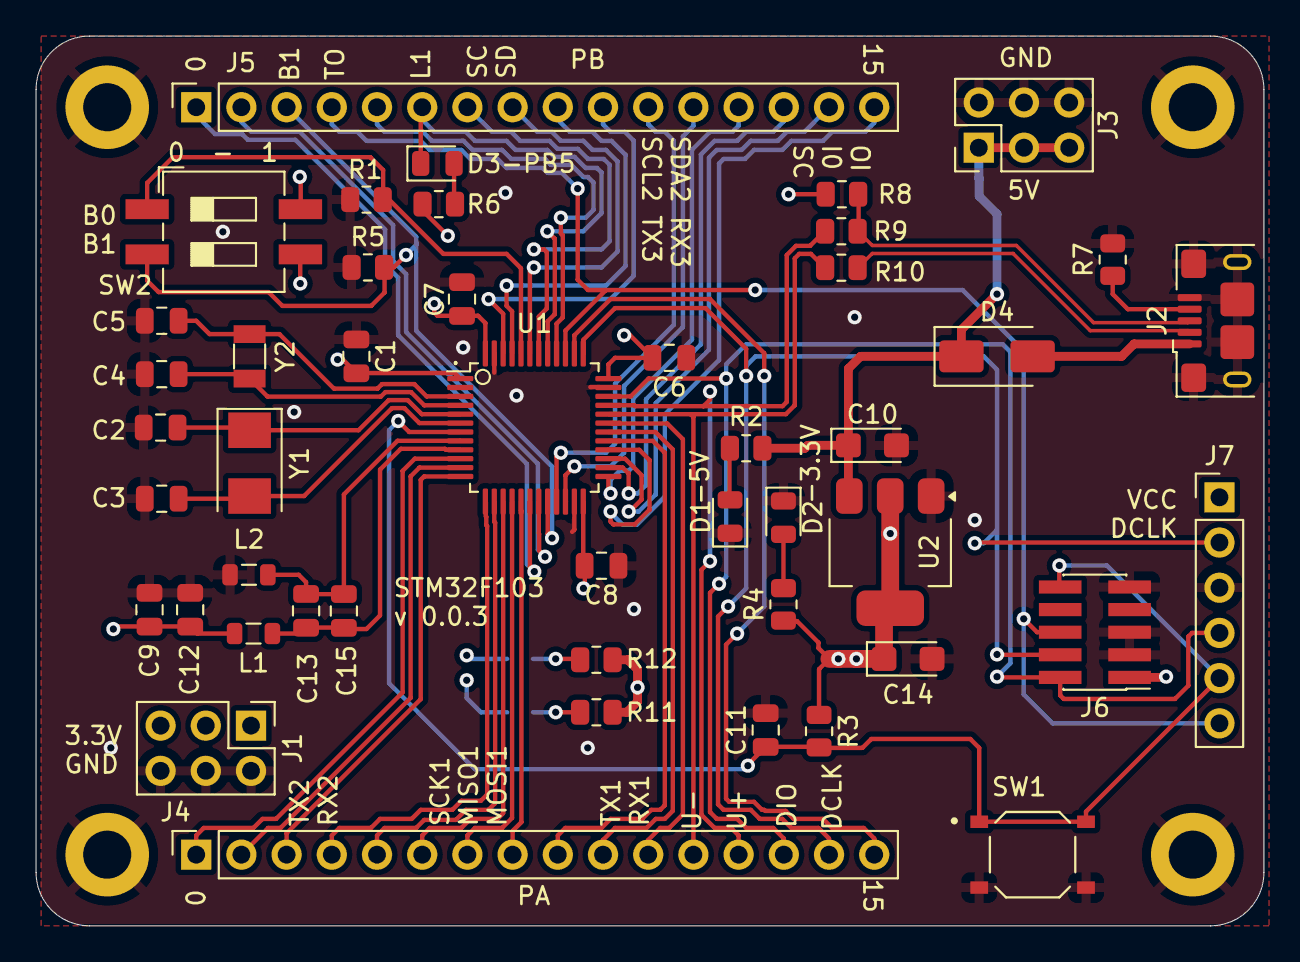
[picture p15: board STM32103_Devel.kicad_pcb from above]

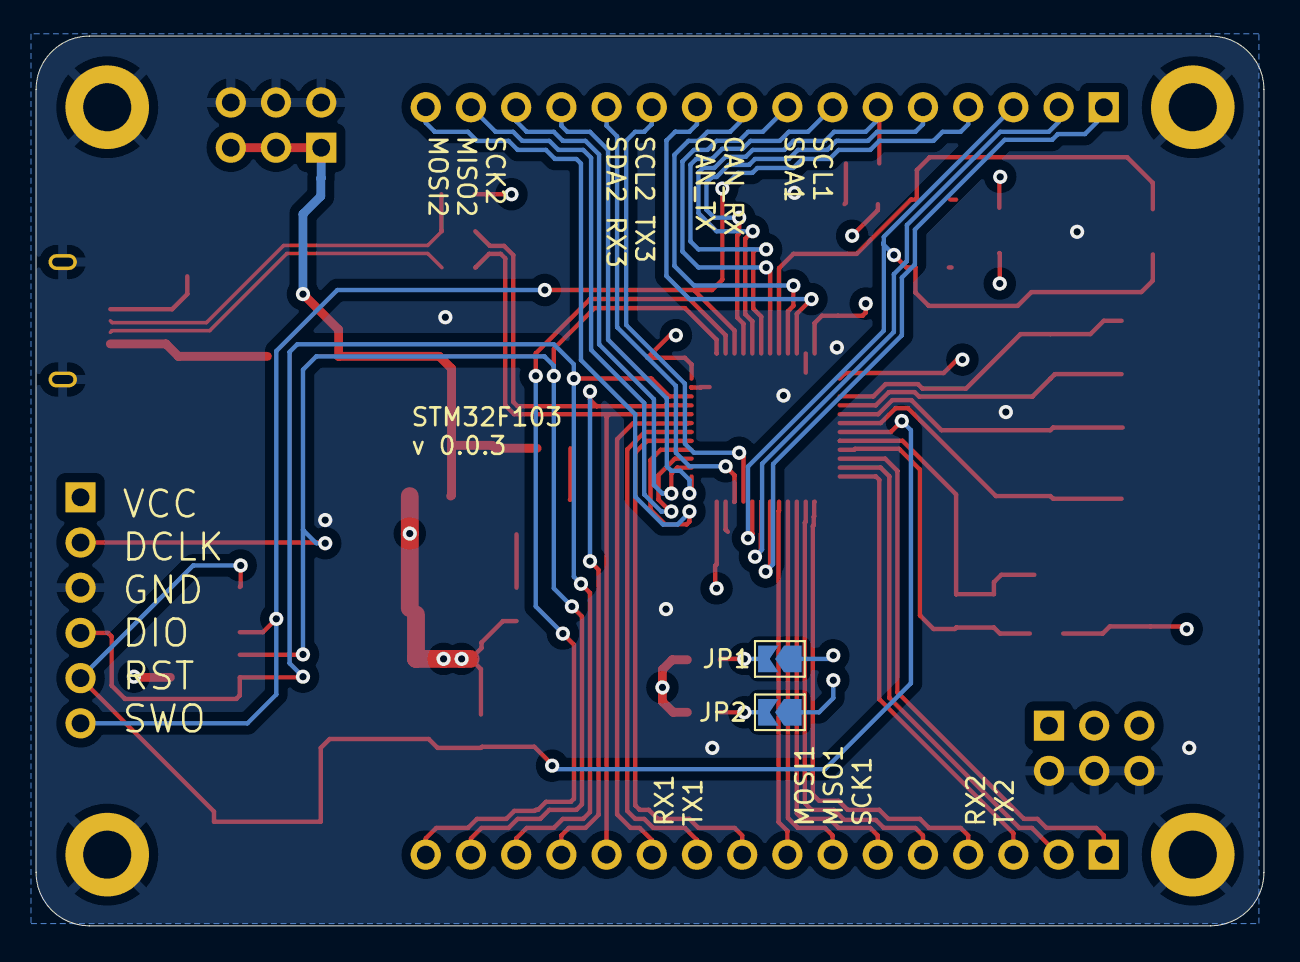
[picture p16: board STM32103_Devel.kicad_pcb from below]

Board: 4 copper layers, 69.0 x 50.0 mm, 52 parts (2 on the bottom side), 52 nets.

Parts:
C1, C6, C7, C8, C11: 100nf; C_0805_2012Metric
C2, C3: 20pf; C_0805_2012Metric
C4, C5: 10pf; C_0805_2012Metric
C9, C13: 1uF; C_0805_2012Metric
C10, C14: 10uf; CP_EIA-3216-18_Kemet-A
C12, C15: 10nF; C_0805_2012Metric
D1: RED; LED_0805_2012Metric
D2: BLUE; LED_0805_2012Metric
D3: GREEN; LED_0805_2012Metric
D4: ss14; D_SMA
H1, H2, H3, H4: MountingHole; MountingHole_2.7mm_M2.5_DIN965_Pad
J1, J3: Conn_02x03_Counter_Clockwise; PinHeader_2x03_P2.54mm_Vertical
J2: USB_B_Micro; USB_Micro-B_Amphenol_10118193-0001LF_Horizontal
J4, J5: Conn_01x16; PinSocket_1x16_P2.54mm_Vertical
J6: Conn_02x05 Odd_Even; PinHeader_2x05_P1.27mm_Vertical_SMD
J7: Conn_01x06; PinHeader_1x06_P2.54mm_Vertical
JP1, JP2: sj_o; SolderJumper-2_P1.3mm_Open_TrianglePad1.0x1.5mm
L1, L2: 10uH; L_0805_2012Metric
R1, R2, R3, R5, R11, R12: 10K; R_0805_2012Metric
R4, R6: 1K; R_0805_2012Metric
R7: 100K; R_0805_2012Metric
R8: 1K5; R_0805_2012Metric
R9, R10: 20; R_0805_2012Metric
SW1: SW_Push; SW_PTS526_SM08_SMTR2_LFS
SW2: SW_DIP_x02; SW_DIP_SPSTx02_Slide_6.7x6.64mm_W8.61mm_P2.54mm_LowProfile
U1: STM32F103CBTx; LQFP-48_7x7mm_P0.5mm
U2: AMS1117-3.3; SOT-223-3_TabPin2
Y1: 8MHz; Crystal_SMD_5032-2Pin_5.0x3.2mm
Y2: 32.768kHz; Crystal_SMD_3215-2Pin_3.2x1.5mm

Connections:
+5V: C10.1, D4.1 (K), J3.1, J3.3, J3.5, R2.1, U2.3 (VI)
/PA0: J4.1, U1.10 (PA0)
/PA1: J4.2, U1.11 (PA1)
/PA2: J4.3, U1.12 (PA2)
/PA3: J4.4, U1.13 (PA3)
/PA4: J4.5, U1.14 (PA4)
/PA5: J4.6, U1.15 (PA5)
/PA6: J4.7, U1.16 (PA6)
/PA7: J4.8, U1.17 (PA7)
/PA8: J4.9, U1.29 (PA8)
/PA9: J4.10, U1.30 (PA9)
/PA10: J4.11, U1.31 (PA10)
/PA11: J4.12, R10.2, U1.32 (PA11)
/PA12: J4.13, R9.1, U1.33 (PA12)
/PA13: J4.14, J6.2, J7.4, U1.34 (PA13)
/PA14: J4.15, J6.4, J7.2, U1.37 (PA14)
/PA15: J4.16, U1.38 (PA15)
/PB0: J5.1, U1.18 (PB0)
/PB1: J5.2, U1.19 (PB1)
/PB2: J5.3, R5.1, SW2.2, U1.20 (PB2)
/PB3: J5.4, J6.6, J7.6, U1.39 (PB3)
/PB4: J5.5, U1.40 (PB4)
/PB5: D3.1 (K), J5.6, U1.41 (PB5)
/PB6: J5.7, JP2.1 (A), U1.42 (PB6)
/PB7: J5.8, JP1.1 (A), U1.43 (PB7)
/PB8: J5.9, U1.45 (PB8)
/PB9: J5.10, U1.46 (PB9)
/PB10: J5.11, U1.21 (PB10)
/PB11: J5.12, U1.22 (PB11)
/PB12: J5.13, U1.25 (PB12)
/PB13: J5.14, U1.26 (PB13)
/PB14: J5.15, U1.27 (PB14)
/PB15: J5.16, U1.28 (PB15)
/STM32F103CB/BOOT0: R1.1, SW2.1, U1.44 (BOOT0)
/STM32F103CB/OSC32_IN: C4.1, U1.4 (PC15), Y2.1
/STM32F103CB/OSC32_OUT: C5.1, U1.3 (PC14), Y2.2
/STM32F103CB/OSC_IN: C2.1, U1.5 (PD0), Y1.1
/STM32F103CB/OSC_OUT: C3.1, U1.6 (PD1), Y1.2
/STM32F103CB/RST: C11.1, J6.10, J7.5, R3.2, SW1.1, U1.7 (NRST)
/STM32F103CB/_VDDA: C13.1, C15.1, L1.1, U1.9 (VDDA)
/USB/USB_N: J2.2 (D-), R10.1
/USB/USB_P: J2.3 (D+), R8.1, R9.2
/USB/VCC_USB: D4.2 (A), J2.1 (VBUS)
GND: C1.1, C2.2, C3.2, C4.2, C5.2, C6.1, C7.1, C8.1, C9.2, C10.2, C11.2, C12.2, C14.2, D1.1 (K), D2.1 (K), H1.1, H2.1, H3.1, H4.1, J1.2, J1.4, J1.6, J2.5 (GND), J2.6 (Shield), J3.2, J3.4, J3.6, J6.3, J6.5, J6.9, J7.3, L2.2, R1.2, R5.2, R7.2, SW1.2, U1.23 (VSS), U1.35 (VSS), U1.47 (VSS), U2.1 (GND)
GNDA: C13.2, C15.2, L2.1, U1.8 (VSSA)
unnamed: D1.2 (A), R2.2
unnamed: D2.2 (A), R4.2
unnamed: D3.2 (A), R6.2
unnamed: J2.4 (ID), R7.1
unnamed: JP1.2 (B), R12.2
unnamed: JP2.2 (B), R11.2
VCC: C1.2, C6.2, C7.2, C8.2, C9.1, C12.1, C14.1, J1.1, J1.3, J1.5, J6.1, J7.1, L1.2, R3.1, R4.1, R6.1, R8.2, R11.1, R12.1, SW2.3, SW2.4, U1.1 (VBAT), U1.24 (VDD), U1.36 (VDD), U1.48 (VDD), U2.2 (VO)

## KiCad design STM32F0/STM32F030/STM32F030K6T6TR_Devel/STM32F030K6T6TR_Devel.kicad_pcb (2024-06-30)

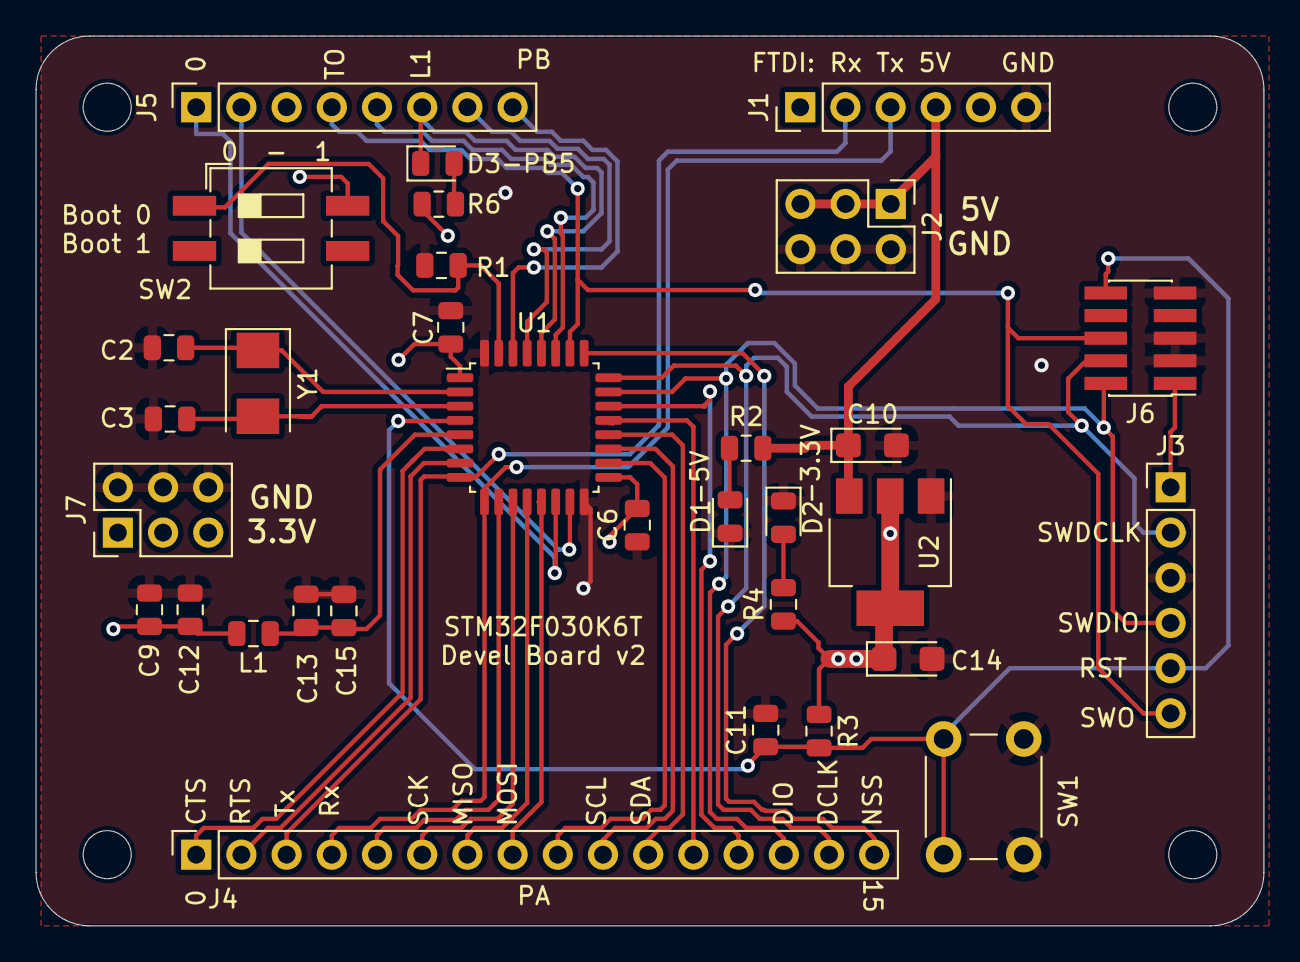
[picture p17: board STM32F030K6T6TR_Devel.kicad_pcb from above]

Board: 4 copper layers, 69.0 x 50.0 mm, 36 parts (0 on the bottom side), 34 nets.

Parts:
C2, C3: 20pf; C_0805_2012Metric
C6, C7, C11: 100nf; C_0805_2012Metric
C9, C13: 1uF; C_0805_2012Metric
C10, C14: 10uf; CP_EIA-3216-18_Kemet-A
C12, C15: 10nF; C_0805_2012Metric
D1: RED; LED_0805_2012Metric
D2: BLUE; LED_0805_2012Metric
D3: GREEN; LED_0805_2012Metric
H1, H2, H3, H4: MountingHole; MountingHole_2.7mm_M2.5
J1, J3: Conn_01x06; PinHeader_1x06_P2.54mm_Vertical
J2, J7: Conn_02x03_Odd_Even; PinHeader_2x03_P2.54mm_Vertical
J4: Conn_01x16; PinSocket_1x16_P2.54mm_Vertical
J5: Conn_01x08; PinSocket_1x08_P2.54mm_Vertical
J6: Conn_02x05 Odd_Even; PinHeader_2x05_P1.27mm_Vertical_SMD
L1: 10uH; L_0805_2012Metric
R1, R2, R3: 10K; R_0805_2012Metric
R4, R6: 1K; R_0805_2012Metric
SW1: SW_Push; SW_PUSH_6mm
SW2: SW_DIP_x02; SW_DIP_SPSTx02_Slide_6.7x6.64mm_W8.61mm_P2.54mm_LowProfile
U1: STM32F030K6Tx; LQFP-32_7x7mm_P0.8mm
U2: AMS1117-3.3; SOT-223-3_TabPin2
Y1: 8MHz; Crystal_SMD_5032-2Pin_5.0x3.2mm

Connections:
+5V: C10.1, J1.4, J2.1, J2.3, J2.5, R2.1, U2.3 (VI)
/PA0: J4.1, U1.6 (PA0)
/PA1: J4.2, U1.7 (PA1)
/PA2: J1.2, J4.3, U1.8 (PA2)
/PA3: J1.3, J4.4, U1.9 (PA3)
/PA4: J4.5, U1.10 (PA4)
/PA5: J4.6, U1.11 (PA5)
/PA6: J4.7, U1.12 (PA6)
/PA7: J4.8, U1.13 (PA7)
/PA8: J4.9, U1.18 (PA8)
/PA9: J4.10, U1.19 (PA9)
/PA10: J4.11, U1.20 (PA10)
/PA11: J4.12, U1.21 (PA11)
/PA12: J4.13, U1.22 (PA12)
/PA13: J3.4, J4.14, J6.2, U1.23 (PA13)
/PA14: J3.2, J4.15, J6.4, U1.24 (PA14)
/PA15: J4.16, U1.25 (PA15)
/PB0: J5.1, U1.14 (PB0)
/PB1: J5.2, U1.15 (PB1)
/PB3: J3.6, J5.4, J6.6, U1.26 (PB3)
/PB4: J5.5, U1.27 (PB4)
/PB5: D3.1 (K), J5.6, U1.28 (PB5)
/PB6: J5.7, U1.29 (PB6)
/PB7: J5.8, U1.30 (PB7)
/STM32F030K6/BOOT0: R1.1, SW2.1, U1.31 (BOOT0)
/STM32F030K6/OSC_IN: C2.1, U1.2 (PF0), Y1.1
/STM32F030K6/OSC_OUT: C3.1, U1.3 (PF1), Y1.2
/STM32F030K6/RST: C11.1, J3.5, J6.10, R3.2, SW1.1, U1.4 (NRST)
/STM32F030K6/_VDDA: C13.1, C15.1, L1.1, U1.5 (VDDA)
GND: C2.2, C3.2, C6.1, C7.1, C9.2, C10.2, C11.2, C12.2, C13.2, C14.2, C15.2, D1.1 (K), D2.1 (K), J1.6, J2.2, J2.4, J2.6, J3.3, J6.3, J6.5, J6.9, J7.2, J7.4, J7.6, R1.2, SW1.2, U1.16 (VSS), U1.32 (VSS), U2.1 (GND)
unnamed: D1.2 (A), R2.2
unnamed: D2.2 (A), R4.2
unnamed: D3.2 (A), R6.2
VCC: C6.2, C7.2, C9.1, C12.1, C14.1, J3.1, J6.1, J7.1, J7.3, J7.5, L1.2, R3.1, R4.1, R6.1, SW2.4, U1.1 (VDD), U1.17 (VDD), U2.2 (VO)

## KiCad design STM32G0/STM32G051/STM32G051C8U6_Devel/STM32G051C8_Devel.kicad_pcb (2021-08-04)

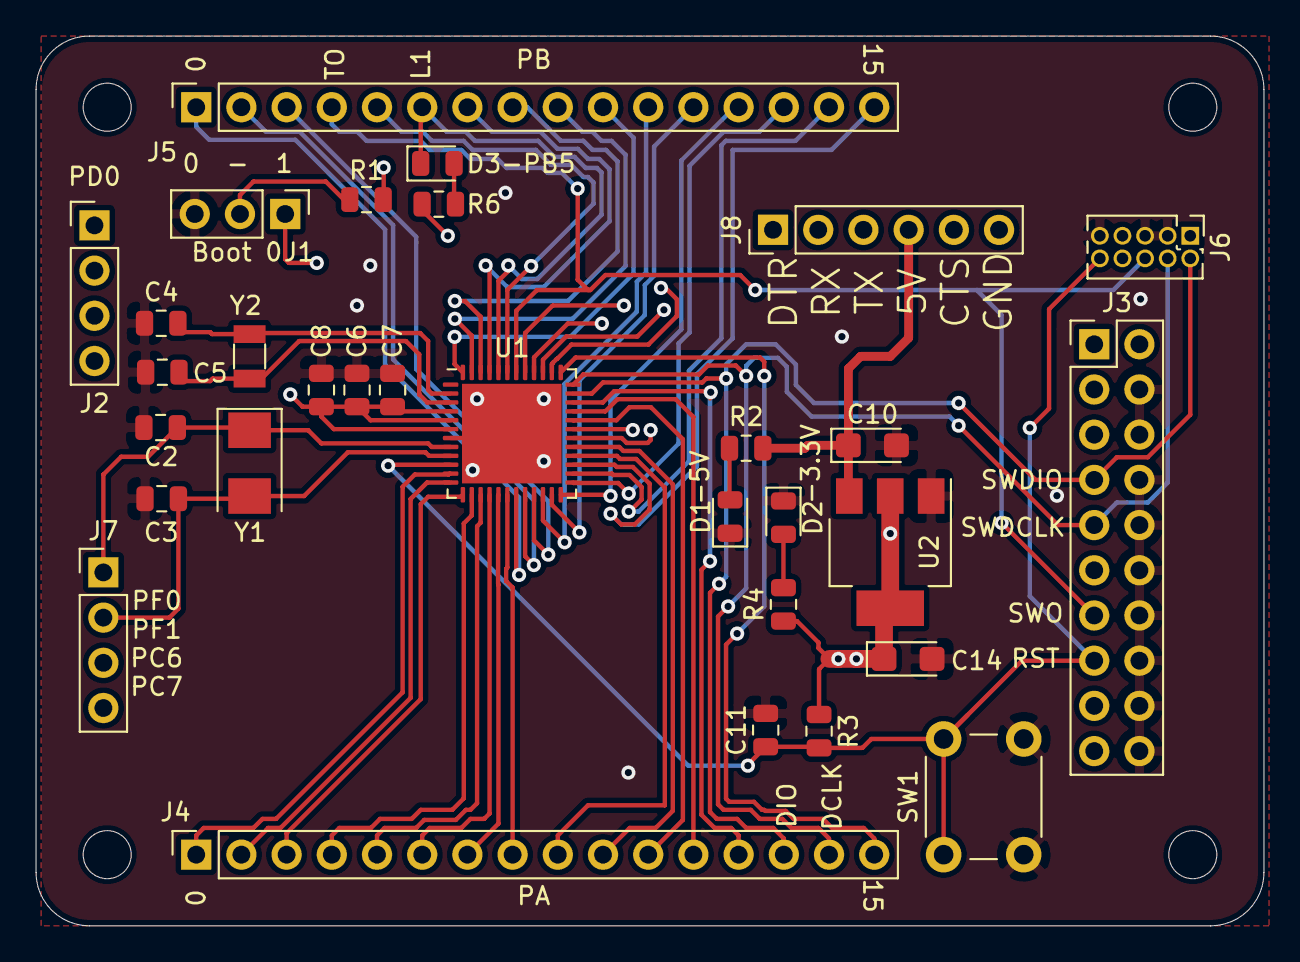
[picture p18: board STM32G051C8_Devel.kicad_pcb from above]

Board: 4 copper layers, 69.0 x 50.0 mm, 35 parts (0 on the bottom side), 50 nets.

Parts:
C2, C3: 20pf; C_0805_2012Metric
C4, C5: 10pf; C_0805_2012Metric
C6, C7, C8, C11: 100nf; C_0805_2012Metric
C10, C14: 10uf; CP_EIA-3216-18_Kemet-A
D1: RED; LED_0805_2012Metric
D2: BLUE; LED_0805_2012Metric
D3: GREEN; LED_0805_2012Metric
H1, H2, H3, H4: MountingHole; MountingHole_2.7mm_M2.5
J1: Conn_01x03; PinHeader_1x03_P2.54mm_Vertical
J2, J7: Conn_01x04; PinHeader_1x04_P2.54mm_Vertical
J3: Conn_02x10_Odd_Even; PinHeader_2x10_P2.54mm_Vertical
J4, J5: Conn_01x16; PinSocket_1x16_P2.54mm_Vertical
J6: Conn_02x05 Odd_Even; PinHeader_2x05_P1.27mm_Vertical
J8: Conn_01x06; PinHeader_1x06_P2.54mm_Vertical
R1, R2, R3: 10K; R_0805_2012Metric
R4, R6: 1K; R_0805_2012Metric
SW1: SW_Push; SW_PUSH_6mm
U1: STM32G051C8Ux; QFN-48-1EP_7x7mm_P0.5mm_EP5.6x5.6mm
U2: AMS1117-3.3; SOT-223-3_TabPin2
Y1: 8MHz; Crystal_SMD_5032-2Pin_5.0x3.2mm
Y2: Crystal; Crystal_SMD_3215-2Pin_3.2x1.5mm

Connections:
+5V: C10.1, J8.4, R2.1, U2.3
/PA0: J4.1, U1.11
/PA1: J4.2, U1.12
/PA2: J4.3, U1.13
/PA3: J4.4, U1.14
/PA4: J4.5, U1.15
/PA5: J4.6, U1.16
/PA6: J4.7, U1.17
/PA7: J4.8, U1.18
/PA8: J4.9, U1.28
/PA9: J4.10, J8.2, U1.29
/PA10: J4.11, J8.3, U1.32
/PA11: J4.12, U1.33
/PA12: J4.13, U1.34
/PA13: J3.7, J4.14, J6.2, U1.35
/PA14: J3.9, J4.15, J6.4, R1.2, U1.36
/PA15: J4.16, U1.37
/PB0: J5.1, U1.19
/PB1: J5.2, U1.20
/PB2: J5.3, U1.21
/PB3: J3.13, J5.4, J6.6, U1.42
/PB4: J5.5, U1.43
/PB5: D3.1, J5.6, U1.44
/PB6: J5.7, U1.45
/PB7: J5.8, U1.46
/PB8: J5.9, U1.47
/PB9: J5.10, U1.48
/PB10: J5.11, U1.22
/PB11: J5.12, U1.23
/PB12: J5.13, U1.24
/PB13: J5.14, U1.25
/PB14: J5.15, U1.26
/PB15: J5.16, U1.27
/PC6: J7.3, U1.30
/PC7: J7.4, U1.31
/PD0: J2.1, U1.38
/PD1: J2.2, U1.39
/PD2: J2.3, U1.40
/PD3: J2.4, U1.41
/PF0: C2.1, J7.1, U1.8, Y1.1
/PF1: C3.1, J7.2, U1.9, Y1.2
/STM32G051/NRST: C11.1, J3.15, J6.10, R3.2, SW1.1, U1.10
/STM32G051/PC14: C4.1, U1.2, Y2.1
/STM32G051/PC15: C5.1, U1.3, Y2.2
GND: C2.2, C3.2, C4.2, C5.2, C6.1, C7.1, C8.1, C10.2, C11.2, C14.2, D1.1, D2.1, J1.3, J3.4, J3.6, J3.8, J3.10, J3.12, J3.14, J3.16, J3.18, J3.20, J6.3, J6.5, J6.9, SW1.2, U1.7, U1.49, U2.1
unnamed: D1.2, R2.2
unnamed: D2.2, R4.2
unnamed: D3.2, R6.2
unnamed: J1.2, R1.1
VCC: C6.2, C7.2, C8.2, C14.1, J1.1, J3.1, J3.2, J6.1, R3.1, R4.1, R6.1, U1.4, U1.5, U1.6, U2.2

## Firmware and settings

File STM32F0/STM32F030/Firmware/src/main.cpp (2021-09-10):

#include <Arduino.h>

#ifndef SERIAL_OUT
#define SERIAL_OUT SerialUSB
#endif

void setup()
{
    SERIAL_OUT.begin(115200);
    pinMode(PIN_TEST_LED, OUTPUT);

}

void loop(){

    while(SERIAL_OUT.available()>0){
        int r = SERIAL_OUT.read();
        SERIAL_OUT.write(r);
    }

    SERIAL_OUT.println("Serial Monitor HIGH");
    digitalWrite(PIN_TEST_LED,HIGH);
    delay(1000);    
    SERIAL_OUT.println("Serial Monitor LOW");
    digitalWrite(PIN_TEST_LED,LOW);
    delay(1000);    
}

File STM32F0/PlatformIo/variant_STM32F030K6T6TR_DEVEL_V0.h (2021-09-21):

/*
 *******************************************************************************
 * Copyright (c) 2020-2021, STMicroelectronics
 * All rights reserved.
 *
 * This software component is licensed by ST under BSD 3-Clause license,
 * the "License"; You may not use this file except in compliance with the
 * License. You may obtain a copy of the License at:
 *                        opensource.org/licenses/BSD-3-Clause
 *
 *******************************************************************************
 */
#if defined(ARDUINO_STM32F030K6T6TR_DEVEL_V0)
#pragma once

/*----------------------------------------------------------------------------
 *        STM32 pins number
 *----------------------------------------------------------------------------*/
#define PA0                     PIN_A0
#define PA1                     PIN_A1
#define PA2                     PIN_A2
#define PA3                     PIN_A3
#define PA4                     PIN_A4
#define PA5                     PIN_A5
#define PA6                     PIN_A6
#define PA7                     PIN_A7
#define PA8                     8
#define PA9                     9
#define PA10                    10
#define PA11                    11
#define PA12                    12
#define PA13                    13
#define PA14                    14
#define PA15                    15
#define PB0                     PIN_A8
#define PB1                     PIN_A9
#define PB3                     18
#define PB4                     19
#define PB5                     20
#define PB6                     21
#define PB7                     22
#define PF0                     23
#define PF1                     24

// Alternate pins number
#define PA6_ALT1                (PA6 | ALT1)
#define PA7_ALT1                (PA7 | ALT1)
#define PA7_ALT2                (PA7 | ALT2)
#define PA7_ALT3                (PA7 | ALT3)
#define PB0_ALT1                (PB0 | ALT1)
#define PB1_ALT1                (PB1 | ALT1)
#define PB1_ALT2                (PB1 | ALT2)

#define NUM_DIGITAL_PINS        25
#define NUM_ANALOG_INPUTS       10

// On-board LED pin number
#ifndef LED_BUILTIN
  #define LED_BUILTIN           PB5
#endif

// On-board user button
#ifndef USER_BTN
  #define USER_BTN              PNUM_NOT_DEFINED
#endif

// SPI definitions
#ifndef PIN_SPI_SS
  #define PIN_SPI_SS            PA4
#endif
#ifndef PIN_SPI_SS1
  #define PIN_SPI_SS1           PA15
#endif
#ifndef PIN_SPI_SS2
  #define PIN_SPI_SS2           PNUM_NOT_DEFINED
#endif
#ifndef PIN_SPI_SS3
  #define PIN_SPI_SS3           PNUM_NOT_DEFINED
#endif
#ifndef PIN_SPI_MOSI
  #define PIN_SPI_MOSI          PA7
#endif
#ifndef PIN_SPI_MISO
  #define PIN_SPI_MISO          PA6
#endif
#ifndef PIN_SPI_SCK
  #define PIN_SPI_SCK           PA5
#endif

// I2C definitions
#ifndef PIN_WIRE_SDA
  #define PIN_WIRE_SDA          PA3
#endif
#ifndef PIN_WIRE_SCL
  #define PIN_WIRE_SCL          PA2
#endif

// Timer Definitions
// Use TIM6/TIM7 when possible as servo and tone don't need GPIO output pin
#ifndef TIMER_TONE
  #define TIMER_TONE            TIM14
#endif
#ifndef TIMER_SERVO
  #define TIMER_SERVO           TIM16
#endif

// UART Definitions
#ifndef SERIAL_UART_INSTANCE
  #define SERIAL_UART_INSTANCE  1
#endif

// Default pin used for generic 'Serial' instance
// Mandatory for Firmata
#ifndef PIN_SERIAL_RX
  #define PIN_SERIAL_RX         PA10
#endif
#ifndef PIN_SERIAL_TX
  #define PIN_SERIAL_TX         PA9
#endif

/*----------------------------------------------------------------------------
 *        Arduino objects - C++ only
 *----------------------------------------------------------------------------*/

#ifdef __cplusplus
  // These serial port names are intended to allow libraries and architecture-neutral
  // sketches to automatically default to the correct port name for a particular type
  // of use.  For example, a GPS module would normally connect to SERIAL_PORT_HARDWARE_OPEN,
  // the first hardware serial port whose RX/TX pins are not dedicated to another use.
  //
  // SERIAL_PORT_MONITOR        Port which normally prints to the Arduino Serial Monitor
  //
  // SERIAL_PORT_USBVIRTUAL     Port which is USB virtual serial
  //
  // SERIAL_PORT_LINUXBRIDGE    Port which connects to a Linux system via Bridge library
  //
  // SERIAL_PORT_HARDWARE       Hardware serial port, physical RX & TX pins.
  //
  // SERIAL_PORT_HARDWARE_OPEN  Hardware serial ports which are open for use.  Their RX & TX
  //                            pins are NOT connected to anything by default.
  #ifndef SERIAL_PORT_MONITOR
    #define SERIAL_PORT_MONITOR   Serial
  #endif
  #ifndef SERIAL_PORT_HARDWARE
    #define SERIAL_PORT_HARDWARE  Serial
  #endif
#endif
#endif

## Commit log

2021-05-25 STM32F103 Devel Board 0.0.1
    [STM32103_Devel.kicad_pcb, STM32103_Devel.sch]
2021-05-25 STM32F103 Devel 0.0.2
    [STM32103_Devel.kicad_pcb, STM32103_Devel.sch]
2021-08-03 New Folder Standard
    [Options.xlsx, STM32103_Devel.kicad_pcb, STM32103_Devel.sch]
2021-08-03 Kicad Reorg
    [STM32103_Devel.kicad_pcb, STM32103_Devel.sch, STM32F103CB.sch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]
2021-08-22 Update to dip sw and local VCC
    [STM32103_Devel.kicad_pcb, STM32103_Devel.sch, STM32F103CB.sch]
2021-08-22 First version of 030
    [STM32F103CB.sch, STM32G051C8_Devel.sch]
2021-08-22 Updated Version FootPrint
    [STM32F030K6.sch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]
2021-08-23 Kibot Split on files
    [STM32F030K6.sch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]
2021-09-03 F030K6 Board
    [STM32F030K6.sch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]
2021-09-10 Uart Changes
    [STM32F030K6T6TR_Devel.kicad_pcb, STM32F030K6T6TR_Devel.sch]
2021-09-10 Doc updated
    [STM32F030K6T6TR_Devel-B_Cu.gbr, STM32F030K6T6TR_Devel-B_Mask.gbr, STM32F030K6T6TR_Devel-B_SilkS.gbr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]
2024-05-17 STM32F030 Updated to kicad8
    [STM32F030K6.kicad_sch, STM32F030K6T6TR_Devel.kicad_pcb, STM32F030K6T6TR_Devel.kicad_sch]
2024-06-29 Add mpn for pcbway
    [STM32F030K6.kicad_sch, STM32F030K6.sch, STM32F030K6T6TR_Devel.kicad_pcb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]
2024-06-30 JLCPCB plugin
    [STM32F030K6T6TR_Devel.kicad_pcb]
2024-06-30 StmF103 updated to kicad8 and kibot
    [STM32103_Devel-B_Cu.gbr, STM32103_Devel-B_Mask.gbr, STM32103_Devel-B_Silkscreen.gbr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]
2024-06-30 MPN from 030
    [STM32103_Devel.kicad_sch, STM32F103CB.kicad_sch, usb.kicad_sch]
2024-07-01 Mpn ids
    [STM32103_Devel.kicad_pcb, STM32103_Devel.kicad_sch, STM32F103CB.kicad_sch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]
2024-07-01 Mov USB
    [STM32103_Devel-B_Cu.gbr, STM32103_Devel-B_Mask.gbr, STM32103_Devel-B_Silkscreen.gbr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]
2024-07-02 Silk Changes
    [STM32103_Devel.kicad_pcb]
2024-07-04 Power Buttons
    [STM32103_Devel.kicad_pcb, STM32103_Devel.kicad_sch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]
2024-07-31 Update Errors
    [STM32103_Devel-B_Cu.gbr, STM32103_Devel-B_Mask.gbr, STM32103_Devel-B_Silkscreen.gbr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]
2024-07-31 PCBWAY zip
2024-08-14 I2C pull-Up
    [STM32103_Devel-B_Cu.gbr, STM32103_Devel-B_Mask.gbr, STM32103_Devel-B_Silkscreen.gbr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]
2024-08-19 Update MPNS and check
    [STM32103_Devel-B_Cu.gbr, STM32103_Devel-B_Mask.gbr, STM32103_Devel-B_Silkscreen.gbr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]
2024-10-12 Docu Actualizada + info silk
    [STM32103_Devel-B_Cu.gbr, STM32103_Devel-B_Mask.gbr, STM32103_Devel-B_Silkscreen.gbr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]
2024-10-24 6Pin conector debug
    [STM32103_Devel-B_Cu.gbr, STM32103_Devel-B_Mask.gbr, STM32103_Devel-B_Silkscreen.gbr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]
2024-10-28 Revision LCSC
    [STM32F030K6.kicad_sch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]
2024-10-28 103 Revision
    [STM32103_Devel-B_Cu.gbr, STM32103_Devel-B_Mask.gbr, STM32103_Devel-B_Silkscreen.gbr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]
